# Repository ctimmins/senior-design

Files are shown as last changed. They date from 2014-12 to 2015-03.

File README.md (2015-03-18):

# SENIOR DESIGN Fall 2014 - Winter 2015
##Various files for the projects throughout senior design
###Agricultural Monitoring System
Our senior design project
###Magnetometer
A silly little project in Fall quarter to establish i2c communication between a magnetometer and psoc5 dev kit
###Check out my [website](www.chadtimmins.com) for further updates!

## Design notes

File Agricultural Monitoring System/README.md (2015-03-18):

<!-- START doctoc generated TOC please keep comment here to allow auto update -->
<!-- DON'T EDIT THIS SECTION, INSTEAD RE-RUN doctoc TO UPDATE -->
**Table of Contents**  *generated with [DocToc](https://github.com/thlorenz/doctoc)*

- [System for Temperature and Evapotranspiration Monitoring (STEM)](#system-for-temperature-and-evapotranspiration-monitoring-stem)
  - [Abstract](#abstract)
  - [Marketing Video](#marketing-video)
  - [Features/Components](#featurescomponents)
      - [PSoC5](#psoc5)
      - [Soil Sensors](#soil-sensors)
      - [Infrared Sensor](#infrared-sensor)
      - [XBee Wireless Radio](#xbee-wireless-radio)
      - [Battery System](#battery-system)
      - [Low Power Consumption](#low-power-consumption)
      - [Beaglebone Black](#beaglebone-black)
      - [Data Store](#data-store)
      - [Web Application and Synchronized Data](#web-application-and-synchronized-data)
      - [Analytics Framework](#analytics-framework)
  - [Future Improvements](#future-improvements)
  - [User Manual](#user-manual)
      - [STEM](#stem)
      - [Beaglebone](#beaglebone)
      - [Firebase](#firebase)
      - [Web Application](#web-application)

<!-- END doctoc generated TOC please keep comment here to allow auto update -->

#System for Temperature and Evapotranspiration Monitoring (STEM)

##Abstract
Monitoring plant health and conserving water are two important considerations in regards to agriculture, especially given the current drought. Plants take in water through rainfall and regular watering and lose water through transpiration. If growers can quantify the amount of water that is available to the plant and how much the plant loses through transpiration, they can irrigate more efficiently. STEM accomplishes both of these goals by monitoring soil moisture and temperature at different depths in the ground around a plant.  STEM also observes the leaf temperature of the plant, which correlates to whether or not the stomata are opened or closed and thus whether or not water is evaporating from the leaves.

The board in the field sends the captured data wirelessly to a coordinator which then uploads the data to a remote database.  From this point, growers can view the data using our web application on a computer or tablet.

##Marketing Video

STEM's Marketing Video (http://www.youtube.com/watch?v=bQJXwqZNXdE)

##Drawings of Systems and Subsystems

##Features/Components
####PSoC5
32 bit ARM Cortex M0 based programmable system on chip a.k.a. the brains of each node.
####Soil Sensors
The multi-level installation of subterraneous sensors gives the user a soil moisture and temperature profile and is useful for monitoring the progression of the water-front.  In other words, our system is able to track how water flows through soil and the conditions that cause it do so.  The soil moisture sensors use transmission line techniques to acquire volumetric water content and are immune to inaccurate measurements due to varying levels of salinity.
####Infrared Sensor
The mounted infrared camera gives the user the ability to detect changes in leaf temperature as a function of time. This is used to determine when the stomates in the leaf closes in the day, which marks the point where the plant stops losing water.
####XBee Wireless Radio
XBee radios are low energy, low bandwidth radios that have a range of around 300 feet.
####Battery System
The device is powered by a 2500 mAh Li-po battery. The battery can be recharged through an external solar panel or a USB phone charger. A analog to digital converter is placed to measure the health of the battery, thereby alerting the user that the battery is low.
####Low Power Consumption
Sleep timers were implemented to reduce overall power consumption. The board itself wakes up roughly every 4 seconds, but only takes and transmits measurements periodically. The frequency of message transmittance is user defined and can easily be adjusted depending on the application.
####Beaglebone Black
We used TI’s Beaglebone Black as the XBee coordinator and internet gateway. An XBee radio was mounted to the Beaglebone and Python scripts were developed to handle all communication to and from the wireless sensors. It also maintains information about multiple nodes such as battery status, and various IR configuration settings. Additional scripts were developed for uploading our data to a secure database (Firebase).
The decision to go with a linux micro computer over Digi’s ConnectPort and proprietary Device Cloud was due to the difficulty of integrating a custom user interface with Digi’s services.
####Data Store
We used Firebase to collect and manage all data.  Firebase was chosen for its simplicity in uploading and retrieving data.  It also provides an easy to use dashboard to manage, view, and download all data.
####Web Application and Synchronized Data
Our web application, along with Firebase as a backend, serves as a simple alternative to Etherios Device Cloud.  Firebase and the relevant javascript API’s allow for real time data synchronization across devices.  This means the user can see live updates of sensor data without having to refresh the page. 
####Analytics Framework
TBD

##Future Improvements

##User Manual
####STEM

####Beaglebone

####Firebase

####Web Application

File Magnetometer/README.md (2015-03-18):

#Driver and GUI for MAG3110
Uses XBee and Matlab to send commands and receive data from magnetometer connected to psoc5
Credit: [Sean Alling](https://github.com/oceanofthelost)

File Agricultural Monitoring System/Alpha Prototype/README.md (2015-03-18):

<!-- START doctoc generated TOC please keep comment here to allow auto update -->
<!-- DON'T EDIT THIS SECTION, INSTEAD RE-RUN doctoc TO UPDATE -->
**Table of Contents**  *generated with [DocToc](https://github.com/thlorenz/doctoc)*

- [Alpha Prototype](#alpha-prototype)
  - [The first hardware prototype of the agricultural monitoring system](#the-first-hardware-prototype-of-the-agricultural-monitoring-system)
    - [PCB Layout](#pcb-layout)
    - [Bill of Materials](#bill-of-materials)

<!-- END doctoc generated TOC please keep comment here to allow auto update -->

#Alpha Prototype
##The first hardware prototype of the agricultural monitoring system
###PCB Layout
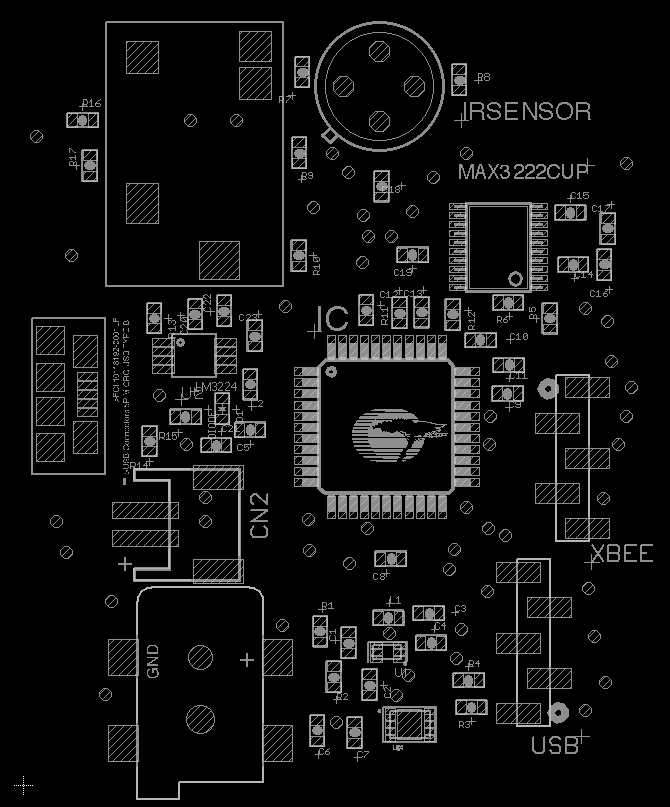
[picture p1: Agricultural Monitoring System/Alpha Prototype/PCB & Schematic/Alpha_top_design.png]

###Bill of Materials
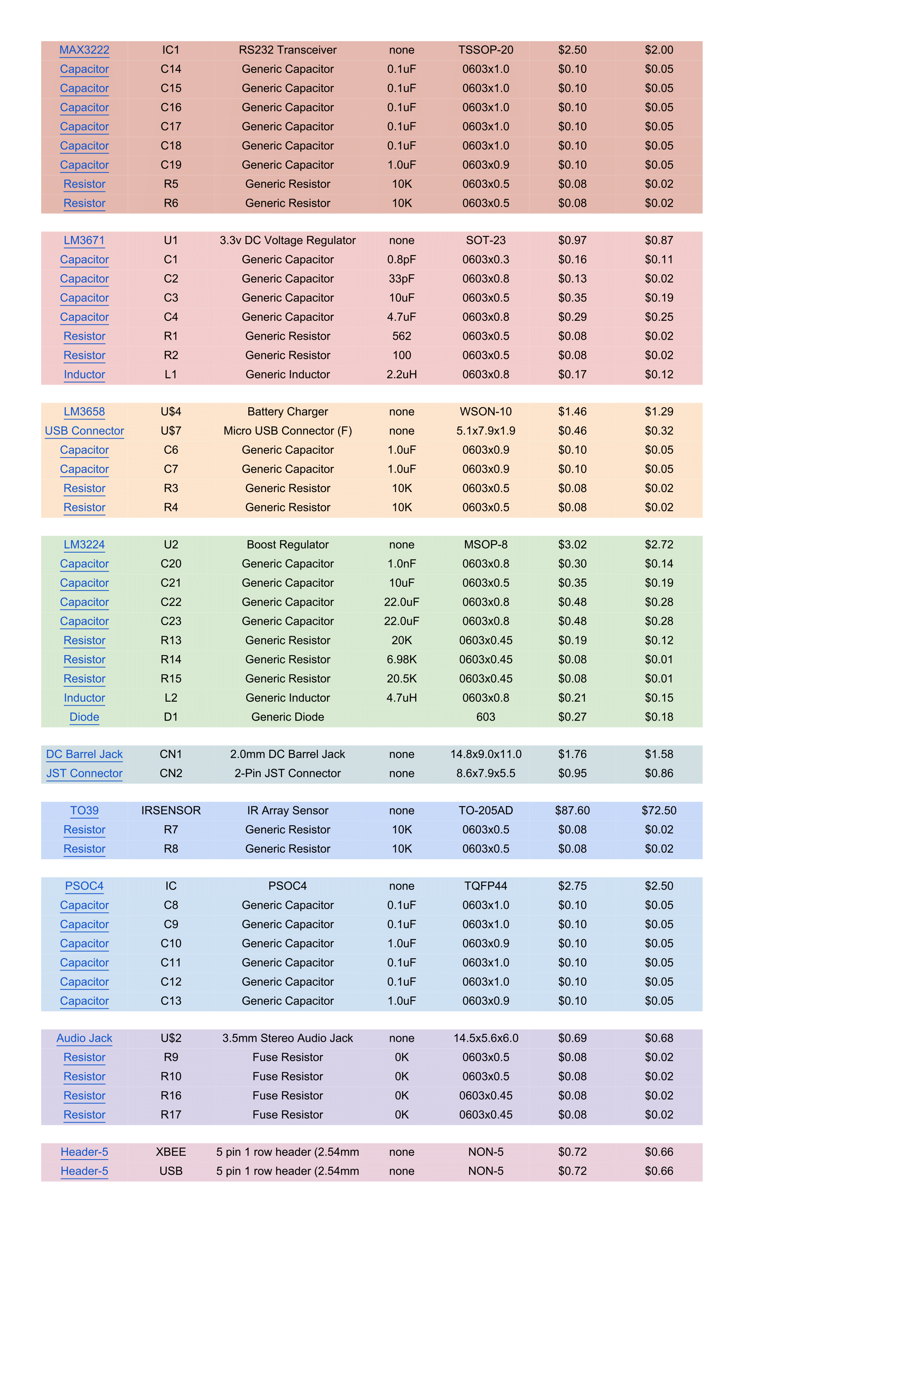
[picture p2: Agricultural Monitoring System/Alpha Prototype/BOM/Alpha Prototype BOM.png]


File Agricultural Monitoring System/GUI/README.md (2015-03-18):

<!-- START doctoc generated TOC please keep comment here to allow auto update -->
<!-- DON'T EDIT THIS SECTION, INSTEAD RE-RUN doctoc TO UPDATE -->
**Table of Contents**  *generated with [DocToc](https://github.com/thlorenz/doctoc)*

- [Graphical User Interface](#graphical-user-interface)
    - [Technologies](#technologies)

<!-- END doctoc generated TOC please keep comment here to allow auto update -->

#Graphical User Interface

###Technologies
* **Firebase** - Backend as a Service to support real time updates from sensors.  3
* **Device Cloud** - Digi's proprietary eco system for monitoring connected devices.  Digi provides a RESTful API that the client-side application will make use of

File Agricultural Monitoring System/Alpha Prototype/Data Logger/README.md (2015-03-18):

<!-- START doctoc generated TOC please keep comment here to allow auto update -->
<!-- DON'T EDIT THIS SECTION, INSTEAD RE-RUN doctoc TO UPDATE -->
**Table of Contents**  *generated with [DocToc](https://github.com/thlorenz/doctoc)*

- [Data Logger for Moisture Sensors](#data-logger-for-moisture-sensors)
  - [SDI-12 Communication](#sdi-12-communication)
    - [Overview](#overview)
    - [Advantages](#advantages)
  - [DDI-Serial Communication](#ddi-serial-communication)
    - [Overview](#overview-1)
    - [Advantages](#advantages-1)
  - [Generalized Schematic of Data Logger System](#generalized-schematic-of-data-logger-system)

<!-- END doctoc generated TOC please keep comment here to allow auto update -->

#Data Logger for Moisture Sensors

##SDI-12 Communication
###Overview
SDI-12 is a standards-based protocol for interfacing sensors to data loggers and data acquisition equipment. Multiple sensors with unique addresses can share a common 3-wire bus (power, ground, and data). Two-way communication between the sensor and logger are possible by sharing the data line for transmit and receive as defined by the standard. Sensor measurements are triggered by protocol command.
###Advantages
* Unique and complex self calibration algorithms can be done in microprocessor- based sensors.
* Sensors can be interchanged without reprogramming the data recorder with calibration or other information.
* Power is supplied to sensors through the interface.

##DDI-Serial Communication
###Overview
The DDI-Serial communications protocol is ideal for systems that have dedicated serial signaling lines for each sensor or use a multiplexer to handle multiple sensors. The serial communications are compatible with many TTL serial implementations that support active-high logic levels using 0-3.6 volts signal levels. When the sensor is first powered, it automatically makes measurements of the integrated transducers then outputs a response over the data line. Systems using this protocol control the sensor excitation to initiate data transfers from the sensor.
###Advantages
* Very easy to interface PSoC to sensor

##Generalized Schematic of Data Logger System
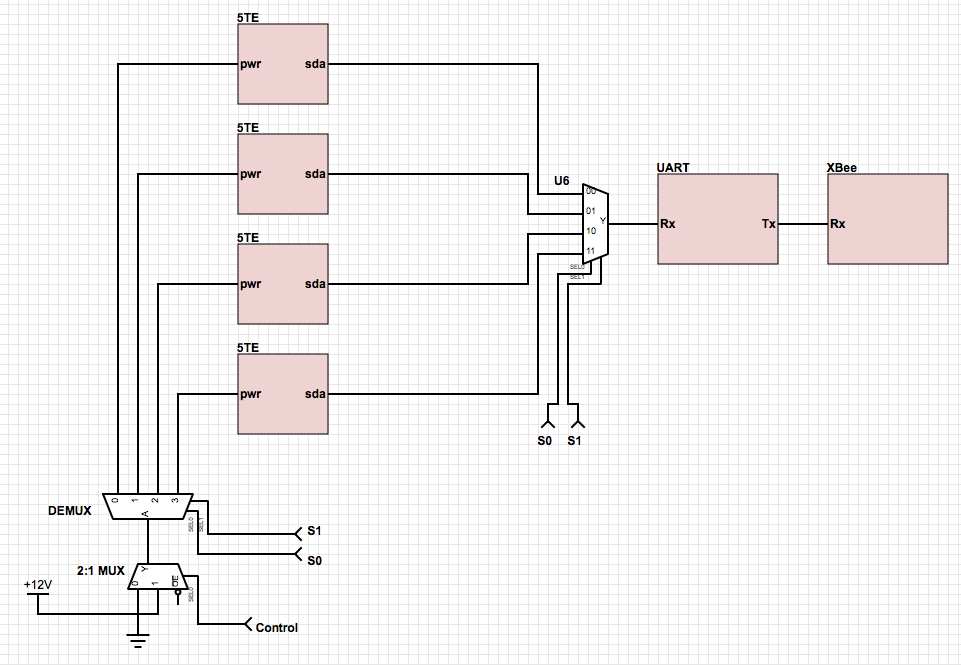
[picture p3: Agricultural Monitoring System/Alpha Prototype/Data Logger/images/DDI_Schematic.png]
alt-tag


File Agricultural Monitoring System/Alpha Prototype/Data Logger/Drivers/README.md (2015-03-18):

<!-- START doctoc generated TOC please keep comment here to allow auto update -->
<!-- DON'T EDIT THIS SECTION, INSTEAD RE-RUN doctoc TO UPDATE -->
**Table of Contents**  *generated with [DocToc](https://github.com/thlorenz/doctoc)*

- [Driver Code for PSoC4 and Decagon 5tm](#driver-code-for-psoc4-and-decagon-5tm)

<!-- END doctoc generated TOC please keep comment here to allow auto update -->

#Driver Code for PSoC4 and Decagon 5tm

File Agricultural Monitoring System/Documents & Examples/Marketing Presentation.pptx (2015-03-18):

## S.T.E.M

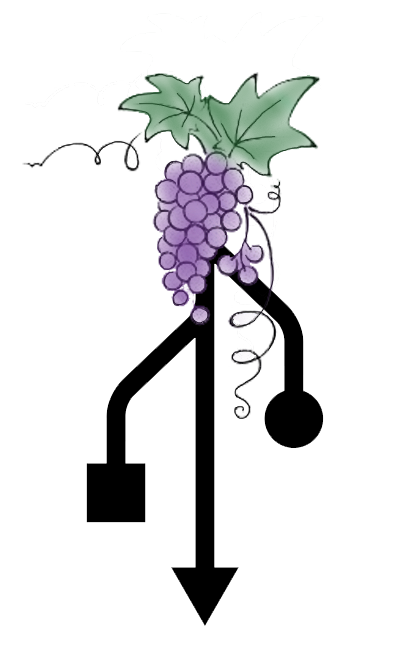
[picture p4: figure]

Team Beta: Advanced Weather Station

Chad Timmins
David Killeen
Erik Zhang
Jeffrey Kung
Robin Johnston

## Why S.T.E.M.?

Against Tule, S.T.E.M.:
- Low Cost vs. $1500
- Lower Price for component replacements vs. $250
- Does not require minimum purchase
- Measures actual soil moisture content
- Measures actual leaf temperature

Against AquaSpy, S.T.E.M.:
- Low Cost vs. $800
- Measures leaf temperature
- Sleeker Design

## Tule’s Design

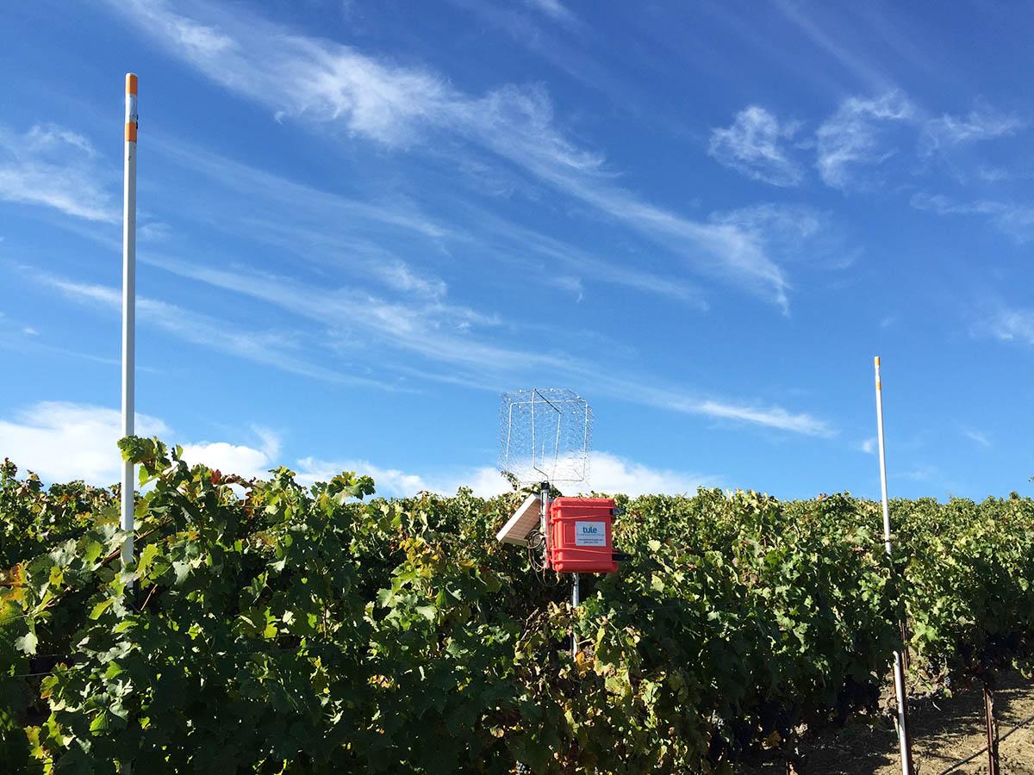
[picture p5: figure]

## AquaSpy’s Design

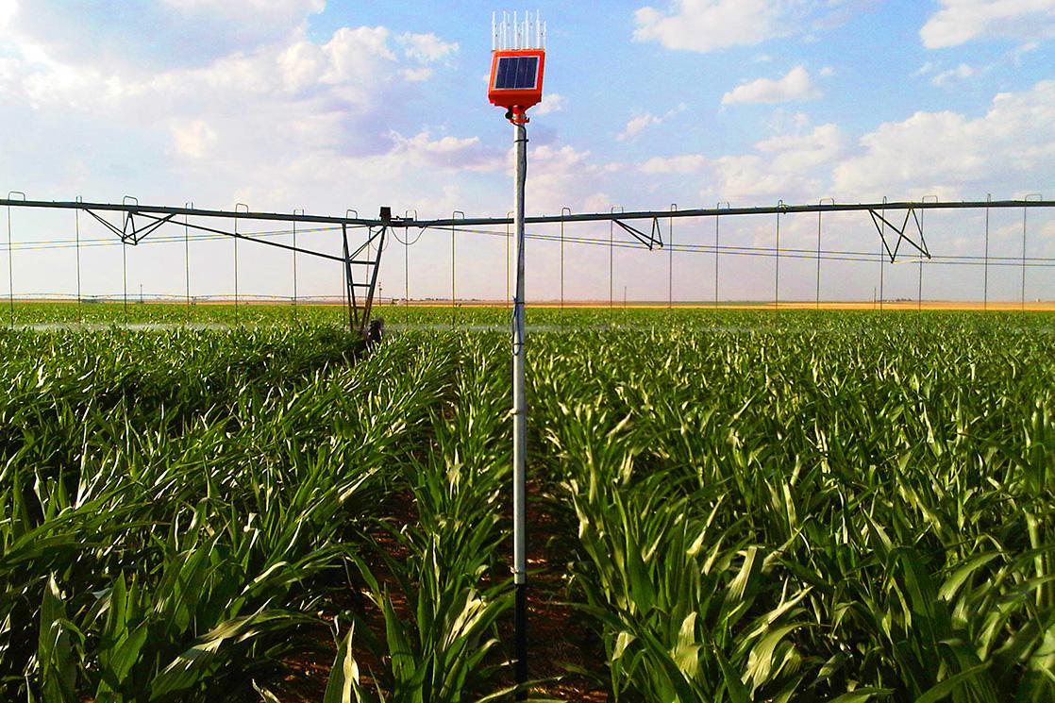
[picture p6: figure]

## Overview

- Monitors soil moisture levels and
leaf temperature
- Cloud storage
- Web interface

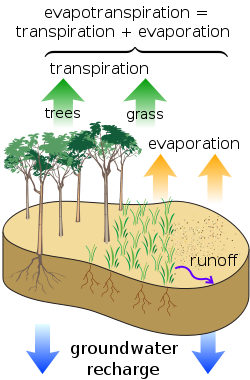
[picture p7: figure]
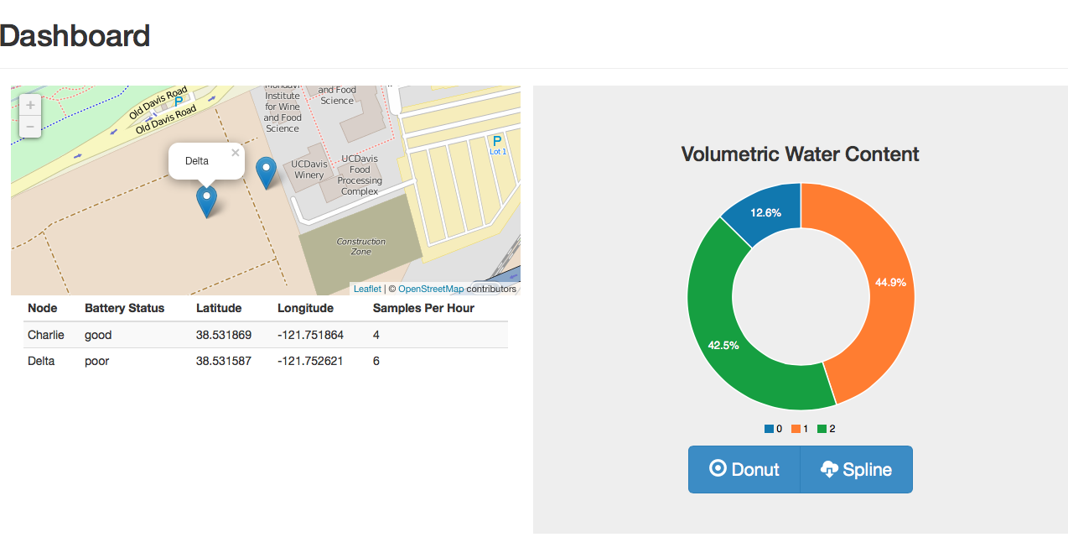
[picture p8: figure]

## Design

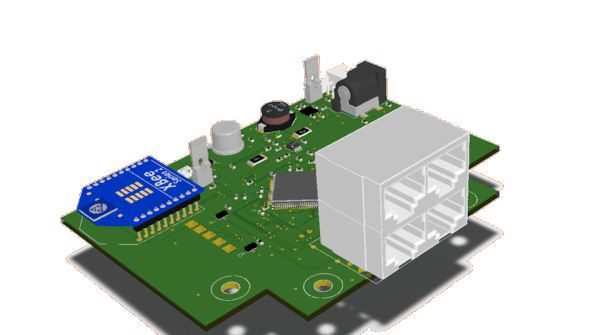
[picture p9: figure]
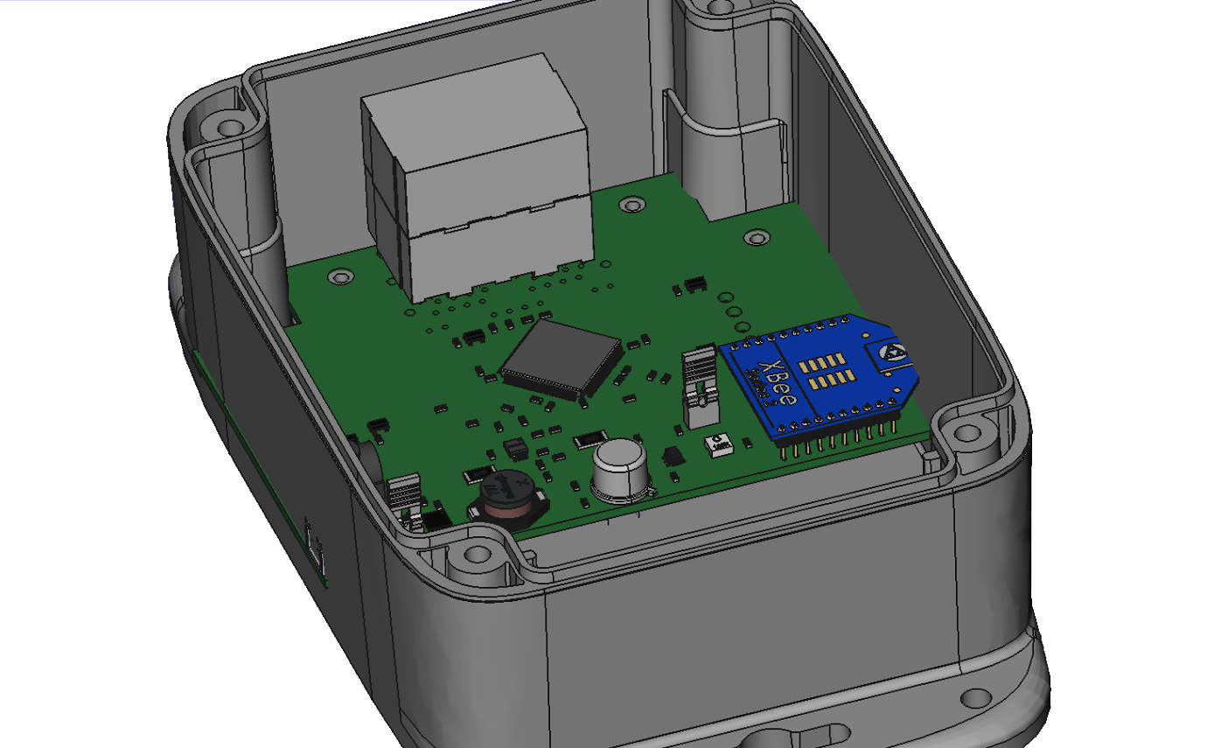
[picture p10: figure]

IR Sensor

DC in

XBee

PSoC 5LP

Ethernet(Vegetronix)

## Power Architecture

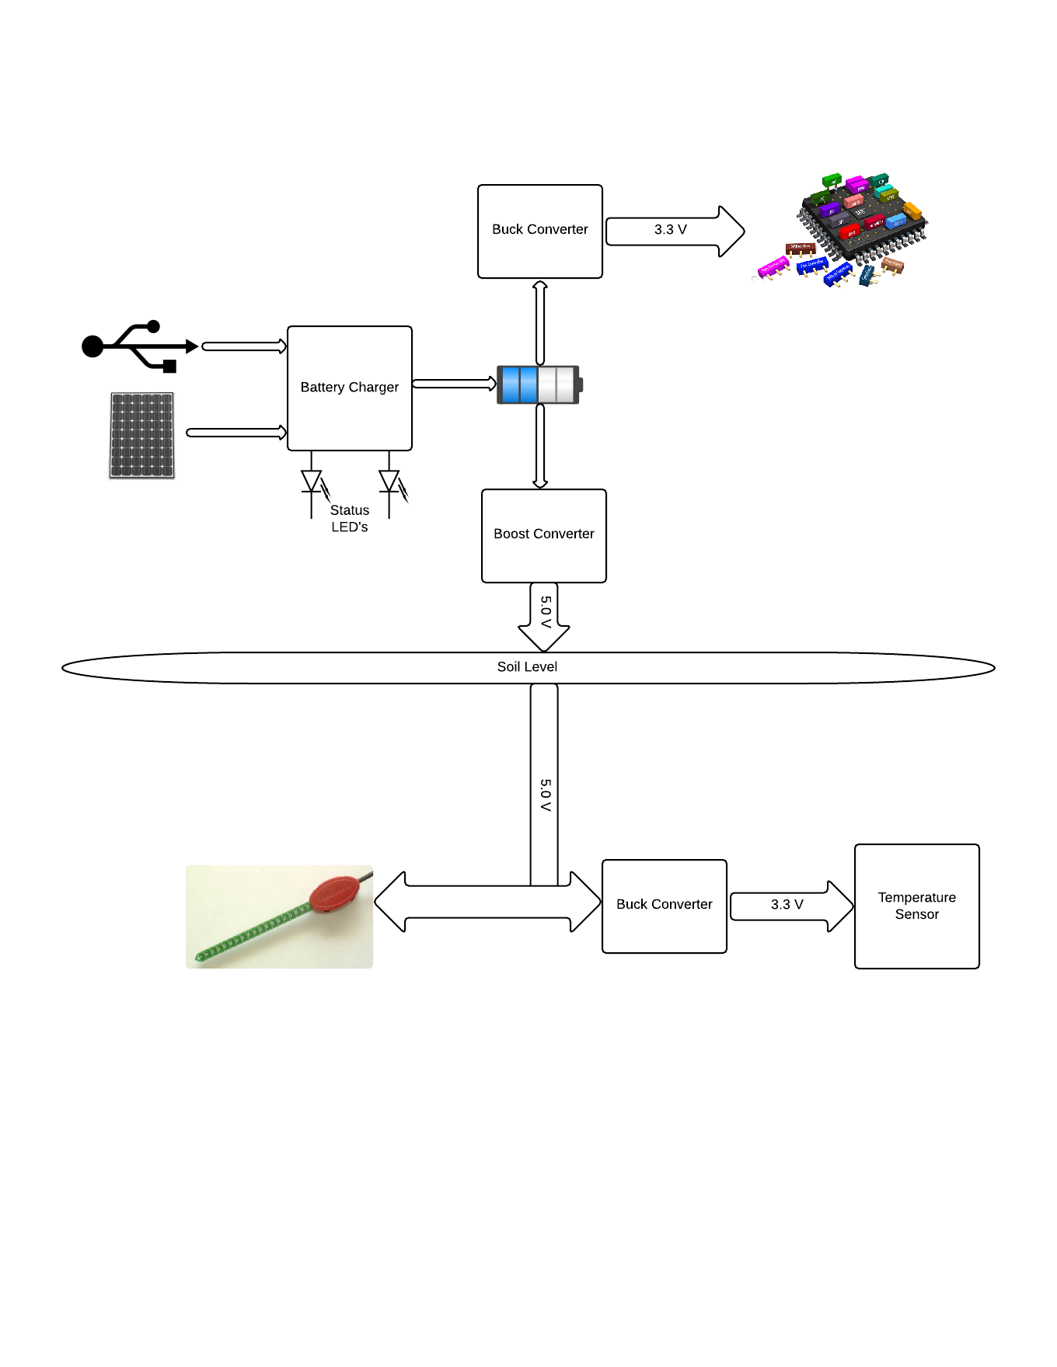
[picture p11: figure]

## Communications

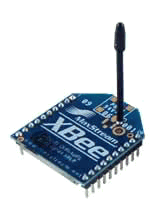
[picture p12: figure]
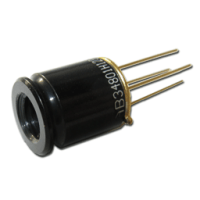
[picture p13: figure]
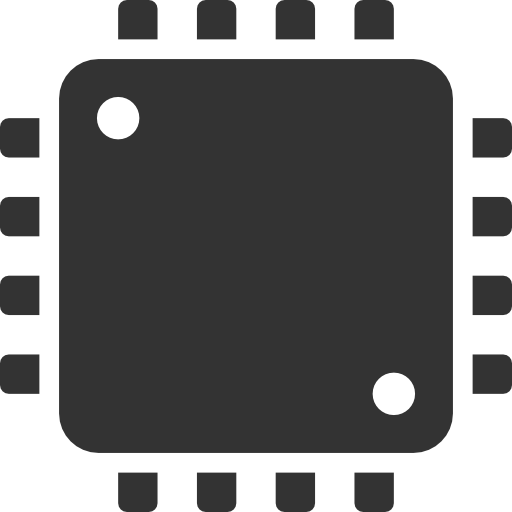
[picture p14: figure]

i2c

uart

i2c

i2c

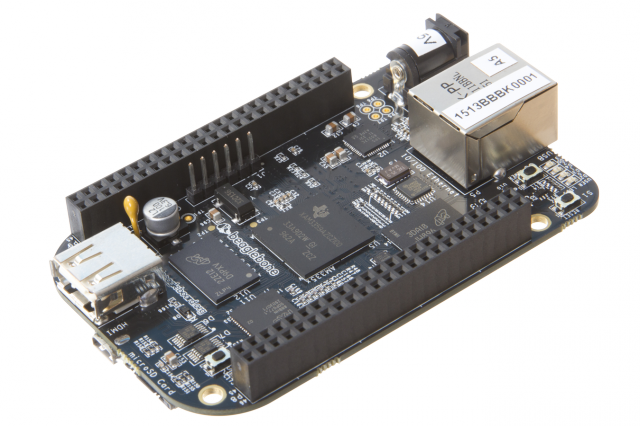
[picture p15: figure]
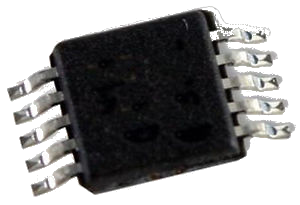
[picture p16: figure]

adc

## Sensors

MLX90620 IR Temperature | Vegetronix Volumetric Water Content | LM75BGD Temperature
Operating Temperature -40ºC to 85ºC Object Temperature-50ºC to 300ºC 16 x 4 Array 60° FOV Accuracy of ±1°C ±3% $88 | Operating Temperature -40ºC to 85ºC Buriable and waterproof Insensitive to salinity Corrosion resistant Accuracy of 2% at 25°C $38 - $54 Each | Operating Temperature -55ºC to 125ºC +/- 2ºC from 25ºC to 100ºC +/- 3ºC from 55ºC to 125ºC temperature resolution of 0.125ºC $0.59 Each

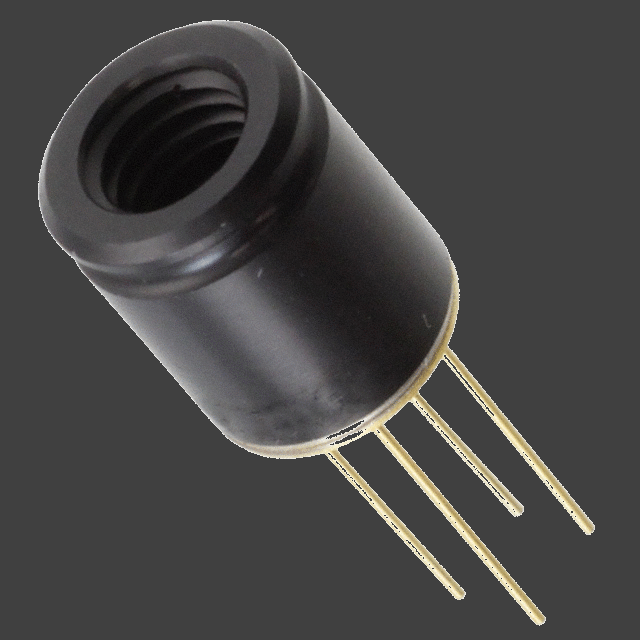
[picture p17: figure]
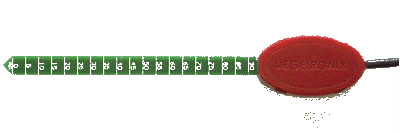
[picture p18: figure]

## State Machine

## Power Consumption

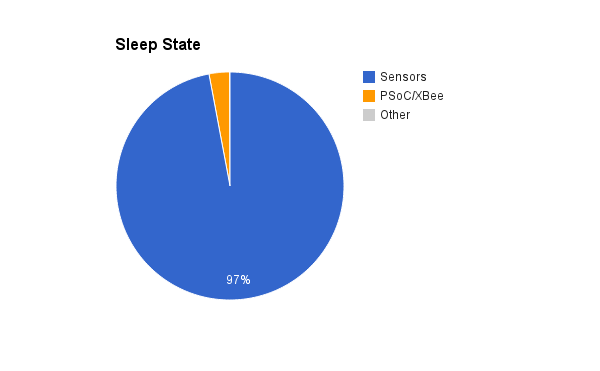
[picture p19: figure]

1.36 mW x 60 min = 1.36 mWh

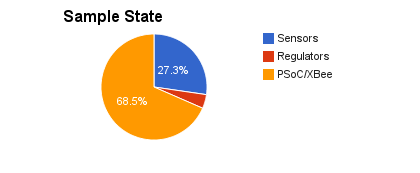
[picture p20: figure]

177.7 mW x 1 sec x 4 = .19744 mWh

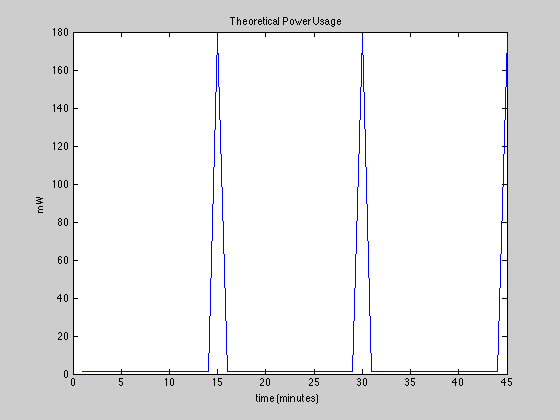
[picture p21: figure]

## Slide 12

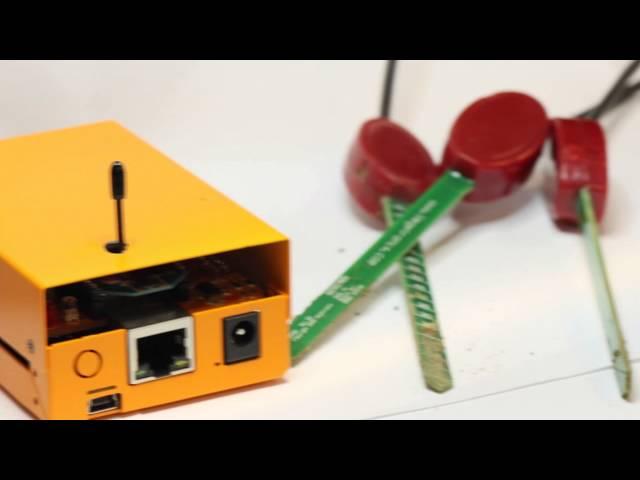
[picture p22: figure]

## Acknowledgements

-Professor André Knoesen
-Dr. Jean-Jacques Lambert
-Nick Hosein and Saneel Khatri

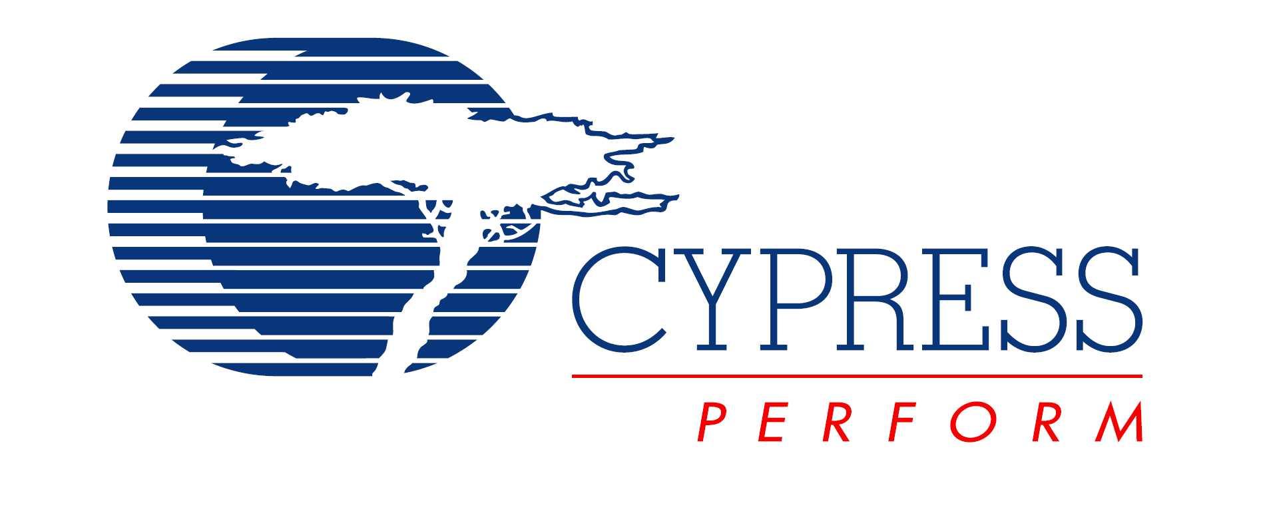
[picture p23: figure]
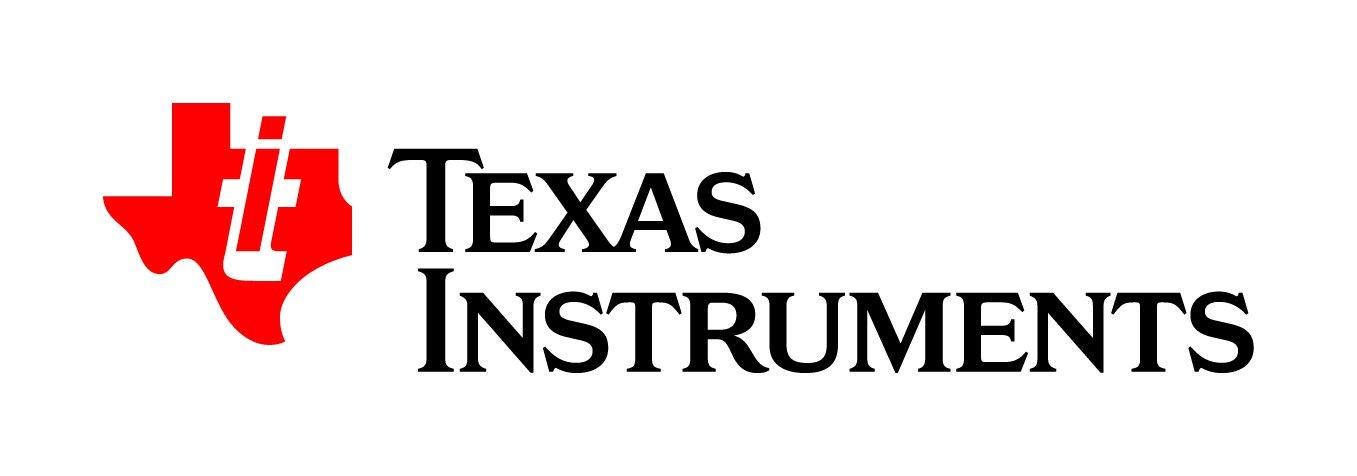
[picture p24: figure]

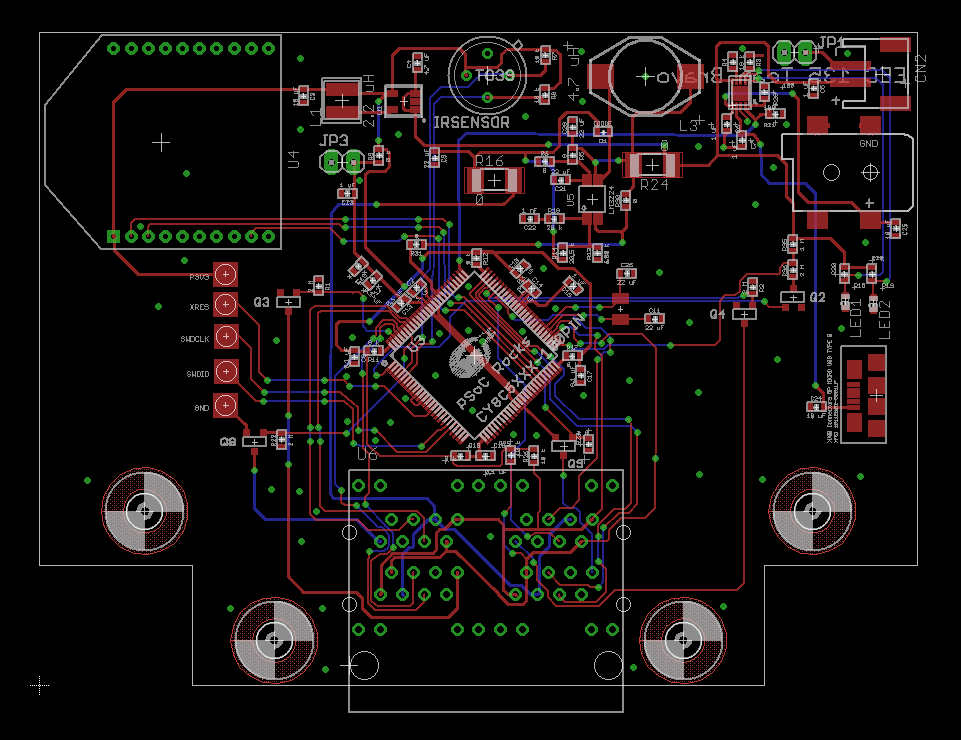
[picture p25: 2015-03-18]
Agricultural Monitoring System/Release/images/Screen Shot 2015-03-14 at 7.27.00 PM.png

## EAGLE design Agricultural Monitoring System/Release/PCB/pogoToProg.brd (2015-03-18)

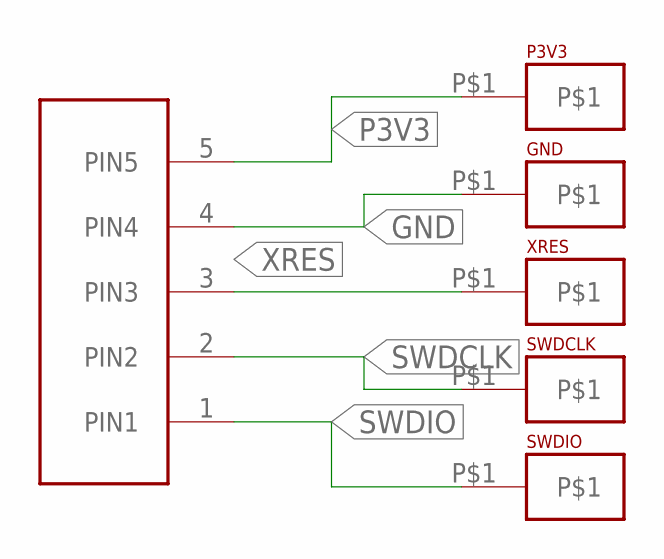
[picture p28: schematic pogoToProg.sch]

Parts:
GND: POGO-MATING
P3V3: POGO-MATING
SWDCLK: POGO-MATING
SWDIO: POGO-MATING
U$1: HEADER-5; NON-5
XRES: POGO-MATING

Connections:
GND: GND.P$1, U$1.4 (PIN4)
P3V3: P3V3.P$1, U$1.5 (PIN5)
SWDCLK: SWDCLK.P$1, U$1.2 (PIN2)
SWDIO: SWDIO.P$1, U$1.1 (PIN1)
XRES: U$1.3 (PIN3), XRES.P$1

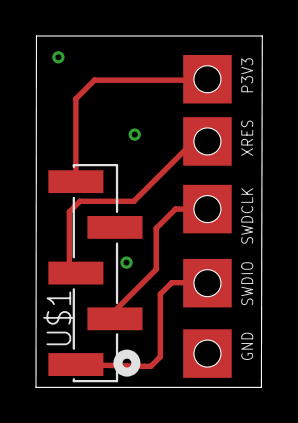
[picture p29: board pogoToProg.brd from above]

Board: 2 copper layers, 12.6 x 19.5 mm, 6 parts (0 on the bottom side), 5 nets.

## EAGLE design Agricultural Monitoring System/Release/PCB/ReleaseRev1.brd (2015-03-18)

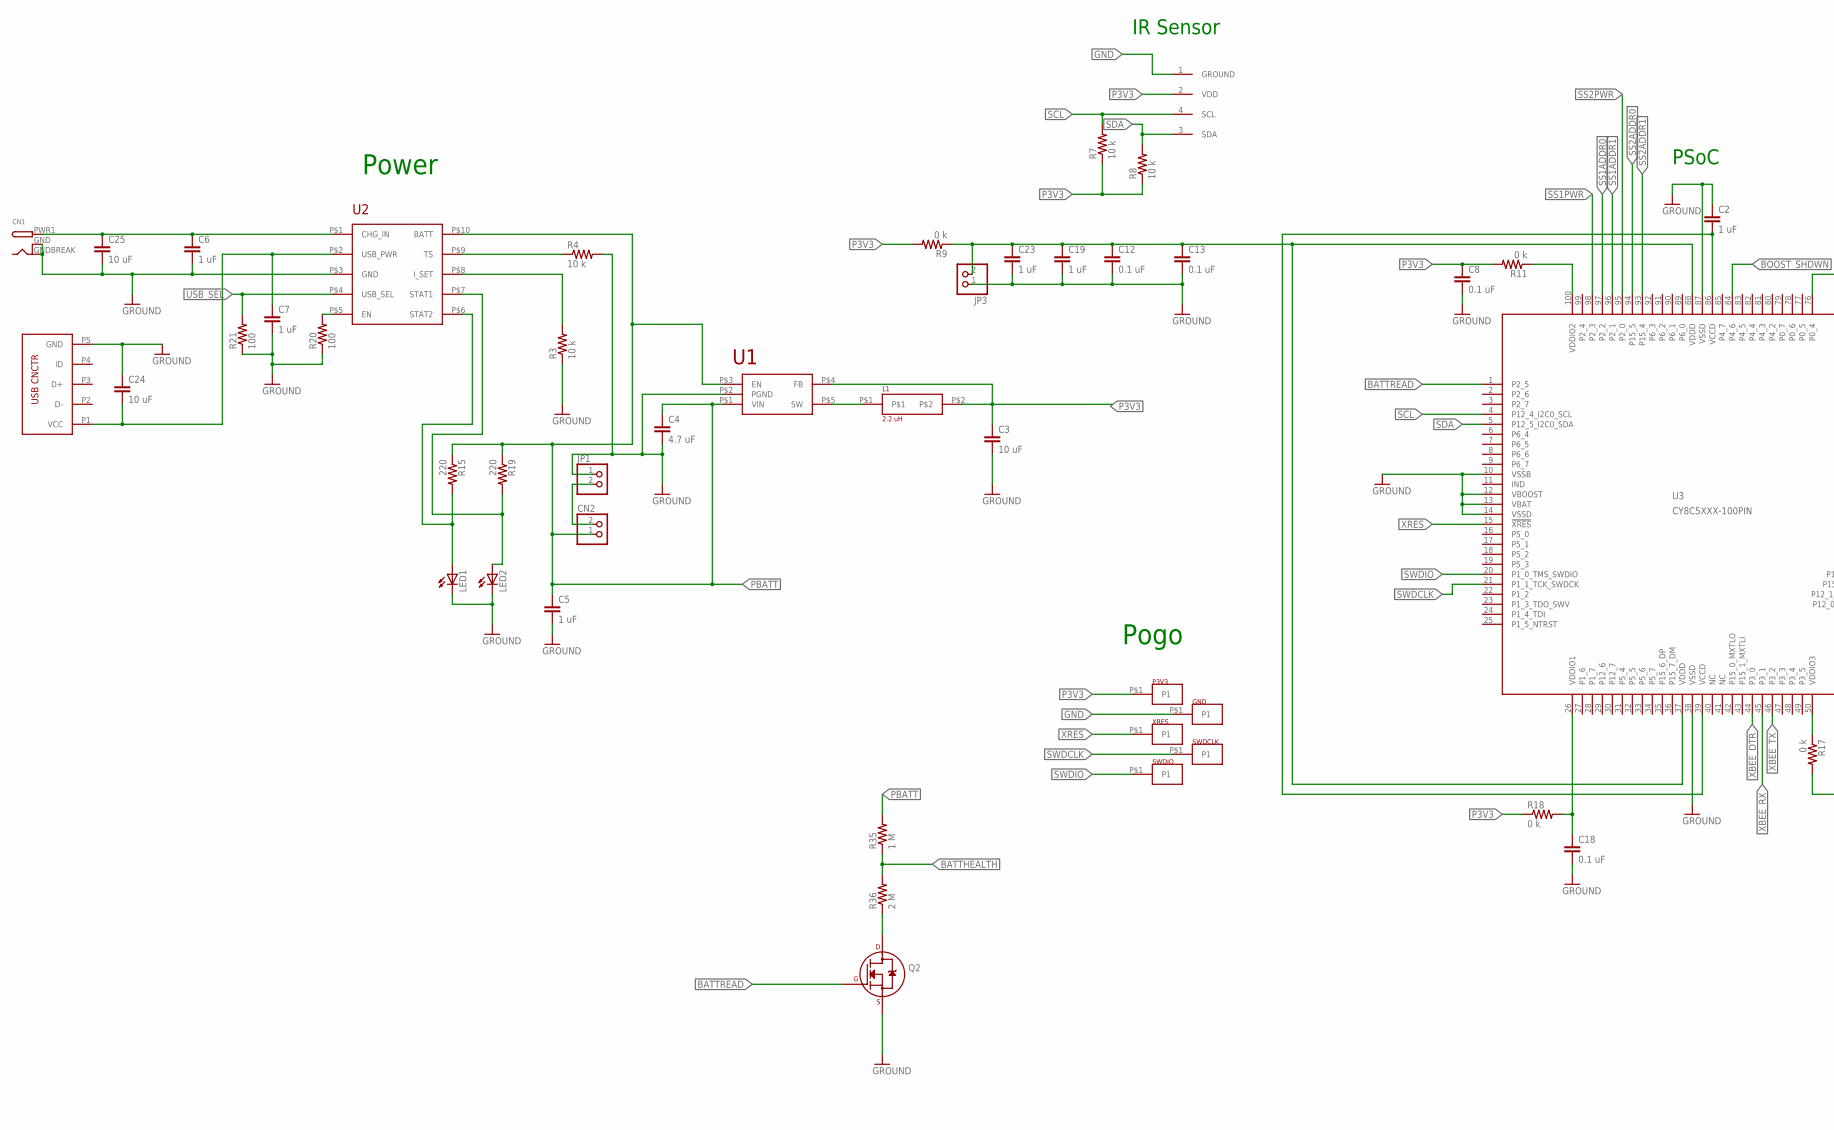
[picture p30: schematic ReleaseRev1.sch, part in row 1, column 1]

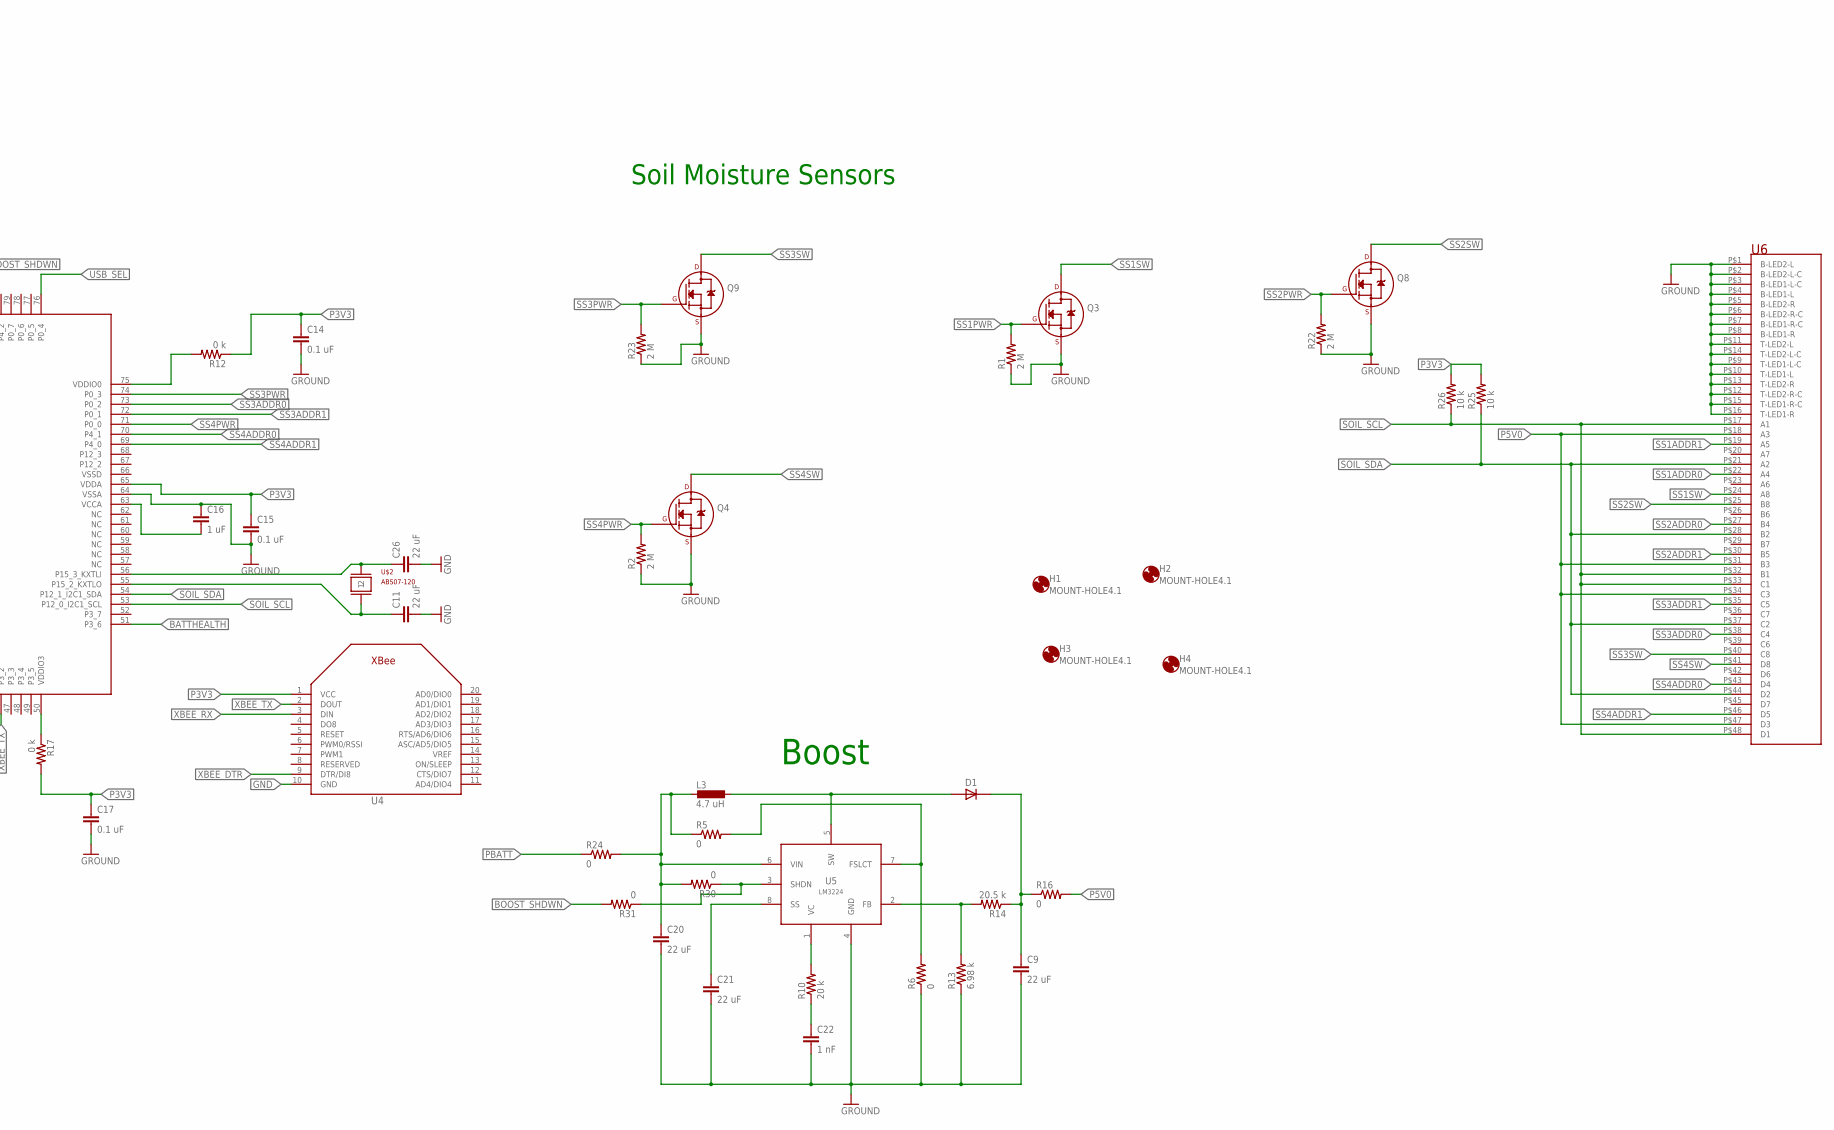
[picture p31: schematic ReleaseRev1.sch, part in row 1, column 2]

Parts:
C2, C5, C6, C7, C16, C19, C23: 1 uF; 0603
C3, C24, C25: 10 uF; 0603
C4: 4.7 uF; 0603
C8, C12, C13, C14, C15, C17, C18: 0.1 uF; 0603
C9, C11, C20, C21, C26: 22 uF; 0603
C22: 1 nF; 0603
CN1: DCBARRELSMT; DCJACK_2MM_SMT
CN2: JST_2PIN-SMT-RA; JST-PH-2-SMT-RA
D1: DIODE; 0603-LED
GND: POGO-MOUNTING
H1, H2, H3, H4: MOUNT-HOLE4.1; 4,1
IRSENSOR: TO39
JP1, JP3: PINHD-1X2; 1X02
L1: LPO3310
L3: 4.7 uH; DO3316P
LED1, LED2: LEDCHIP-LED0603; CHIP-LED0603
P3V3: POGO-MOUNTING
Q2, Q3, Q4, Q8, Q9: 2N7000_SOT23; SOT-23
R1, R2, R22, R23, R36: 2 M; 0603
R3, R4, R7, R8, R25, R26: 10 k; 0603
R5, R6, R30, R31: 0; 0603
R9, R11, R12, R17, R18: 0 k; 0603
R10: 20 k; 0603
R13: 6.98 k; 0603
R14: 20.5 k; 0603
R15, R19: 220; 0603
R16, R24: 0; R2010
R20, R21: 100; 0603
R35: 1 M; 0603
SWDCLK: POGO-MOUNTING
SWDIO: POGO-MOUNTING
U1: LM3671-407564
U2: LM3658
U3: CY8C5XXX-100PIN; TQFP-14X14-100
U4: XBEE
U5: LM3224; MSOP-8
U6: RJSAE-5380-04
U$1: FCI10118192-0001LF
U$2: ABS07-120; 2-SMD
XRES: POGO-MOUNTING

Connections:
BATTHEALTH: R35.1, R36.2, U3.51 (P3_6)
BATTREAD: Q2.1 (G), U3.1 (P2_5)
BOOST_SHDWN: R31.2, U3.84 (P4_6)
GND: C2.1, C3.2, C4.2, C5.2, C6.2, C7.2, C8.2, C9.2, C11.2, C12.2, C13.2, C14.2, C15.2, C16.1, C17.2, C18.2, C19.2, C20.2, C21.2, C22.2, C23.2, C24.1, C25.2, C26.2, CN1.GND (GNDBREAK), CN1.GNDBREAK (GND), GND.P$1, IRSENSOR.1 (GROUND), JP1.1, JP3.1, LED1.C, LED2.C, Q2.2 (S), Q3.2 (S), Q4.2 (S), Q8.2 (S), Q9.2 (S), R1.1, R2.1, R3.1, R4.2, R6.1, R13.1, R20.1, R21.1, R22.1, R23.1, U1.P$2 (PGND), U2.P$3 (GND), U3.10 (VSSB), U3.12 (VBOOST), U3.13 (VBAT), U3.14 (VSSD), U3.38 (VSSD), U3.64 (VSSA), U3.87 (VSSD), U4.10 (GND), U5.4 (GND), U6.P$1 (B-LED2-L), U6.P$2 (B-LED2-L-C), U6.P$3 (B-LED1-L-C), U6.P$4 (B-LED1-L), U6.P$5 (B-LED2-R), U6.P$6 (B-LED2-R-C), U6.P$7 (B-LED1-R-C), U6.P$8 (B-LED1-R), U6.P$9 (T-LED1-L-C), U6.P$10 (T-LED1-L), U6.P$11 (T-LED2-L), U6.P$12 (T-LED2-R-C), U6.P$13 (T-LED2-R), U6.P$14 (T-LED2-L-C), U6.P$15 (T-LED1-R-C), U6.P$16 (T-LED1-R), U$1.P5 (GND)
unnamed: R20.2, U2.P$5 (EN)
unnamed: R3.2, U2.P$8 (I_SET)
unnamed: C21.1, U5.8 (SS)
unnamed: C26.1, U3.56 (P15_3_KXTLI), U$2.1
unnamed: C6.1, C25.1, CN1.PWR1 (PWR), U2.P$1 (CHG_IN)
unnamed: C18.1, R18.2, U3.26 (VDDIO1)
unnamed: D1.A, L3.2, U5.5 (SW)
unnamed: R4.1, U2.P$9 (TS)
unnamed: R10.2, U5.1 (VC)
unnamed: CN2.2 (1), JP1.2
unnamed: C22.1, R10.1
unnamed: R13.2, R14.2, U5.2 (FB)
unnamed: C2.2, U3.39 (VCCD), U3.86 (VCCD)
unnamed: Q2.3 (D), R36.1
unnamed: C16.2, U3.63 (VCCA)
unnamed: R5.2, R6.2, U5.7 (FSLCT)
unnamed: C11.1, U3.55 (P15_2_KXTLO), U$2.2
unnamed: R12.2, U3.75 (VDDIO0)
unnamed: R11.1, U3.100 (VDDIO2)
unnamed: C12.1, C13.1, C19.1, C23.1, JP3.2, R9.1, U3.37 (VDDD), U3.88 (VDDD)
unnamed: R17.1, U3.50 (VDDIO3)
unnamed: LED2.A, R19.2, U2.P$7 (STAT1)
unnamed: LED1.A, R15.2, U2.P$6 (STAT2)
unnamed: L1.P$1, U1.P$5 (SW)
unnamed: R30.1, R31.1, U5.3 (SHDN)
P: C20.1, L3.1, R5.1, R24.2, R30.2, U5.6 (VIN)
P3V3: C3.1, C8.1, C14.1, C15.1, C17.1, IRSENSOR.2 (VDD), L1.P$2, P3V3.P$1, R7.1, R8.1, R9.2, R11.2, R12.1, R17.2, R18.1, R25.2, R26.2, U1.P$4 (FB), U3.65 (VDDA), U4.1 (VCC)
P5: C9.1, D1.C, R14.1, R16.1
P5V0: R16.2, U6.P$18 (A3), U6.P$31 (B3), U6.P$34 (C3), U6.P$47 (D3)
PBATT: C4.1, C5.1, CN2.1 (2), R15.1, R19.1, R24.1, R35.2, U1.P$1 (VIN), U1.P$3 (EN), U2.P$10 (BATT)
SCL: IRSENSOR.4 (SCL), R7.2, U3.4 (P12_4_I2C0_SCL)
SDA: IRSENSOR.3 (SDA), R8.2, U3.5 (P12_5_I2C0_SDA)
SOIL_SCL: R26.1, U3.53 (P12_0_I2C1_SCL), U6.P$17 (A1), U6.P$32 (B1), U6.P$33 (C1), U6.P$48 (D1)
SOIL_SDA: R25.1, U3.54 (P12_1_I2C1_SDA), U6.P$21 (A2), U6.P$28 (B2), U6.P$37 (C2), U6.P$44 (D2)
SS1ADDR0: U3.97 (P2_2), U6.P$22 (A4)
SS1ADDR1: U3.96 (P2_1), U6.P$19 (A5)
SS1PWR: Q3.1 (G), R1.2, U3.98 (P2_3)
SS1SW: Q3.3 (D), U6.P$24 (A8)
SS2ADDR0: U3.94 (P15_5), U6.P$27 (B4)
SS2ADDR1: U3.93 (P15_4), U6.P$30 (B5)
SS2PWR: Q8.1 (G), R22.2, U3.95 (P2_0)
SS2SW: Q8.3 (D), U6.P$25 (B8)
SS3ADDR0: U3.73 (P0_2), U6.P$38 (C4)
SS3ADDR1: U3.72 (P0_1), U6.P$35 (C5)
SS3PWR: Q9.1 (G), R23.2, U3.74 (P0_3)
SS3SW: Q9.3 (D), U6.P$40 (C8)
SS4ADDR0: U3.70 (P4_1), U6.P$43 (D4)
SS4ADDR1: U3.69 (P4_0), U6.P$46 (D5)
SS4PWR: Q4.1 (G), R2.2, U3.71 (P0_0)
SS4SW: Q4.3 (D), U6.P$41 (D8)
SWDCLK: SWDCLK.P$1, U3.21 (P1_1_TCK_SWDCK)
SWDIO: SWDIO.P$1, U3.20 (P1_0_TMS_SWDIO)
USB: C7.1, C24.2, U2.P$2 (USB_PWR), U$1.P1 (VCC)
USB_SEL: R21.2, U2.P$4 (USB_SEL), U3.76 (P0_4)
XBEE_DTR: U3.44 (P3_0), U4.9 (DTR/DI8)
XBEE_RX: U3.45 (P3_1), U4.3 (DIN)
XBEE_TX: U3.46 (P3_2), U4.2 (DOUT)
XRES: U3.15 (!XRES!), XRES.P$1

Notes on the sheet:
PSoC
IR Sensor
Boost
Pogo
Power
Soil Moisture Sensors

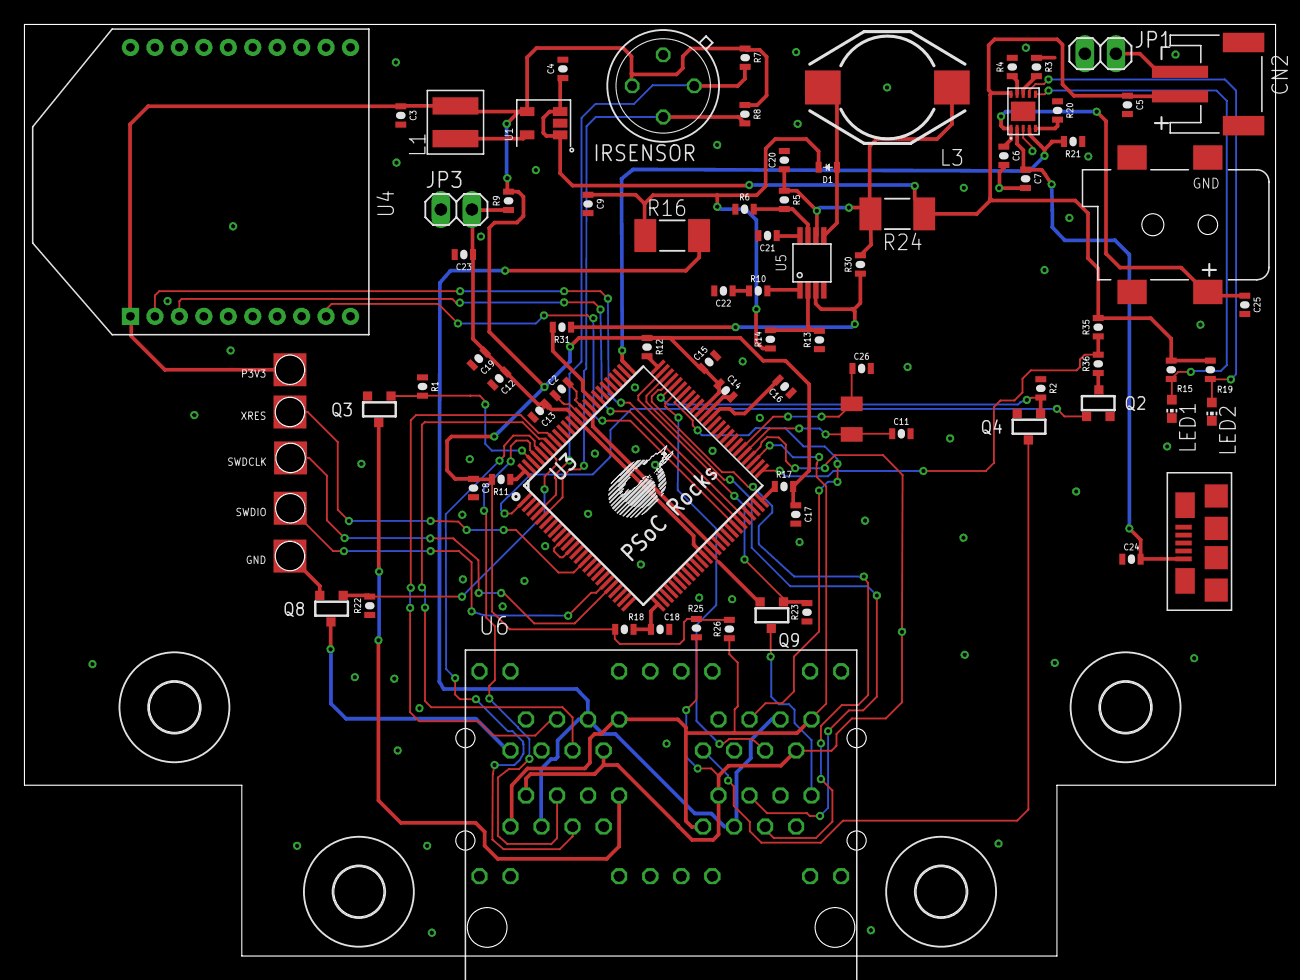
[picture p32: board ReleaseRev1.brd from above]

Board: 2 copper layers, 102.3 x 76.2 mm, 86 parts (0 on the bottom side), 62 nets.

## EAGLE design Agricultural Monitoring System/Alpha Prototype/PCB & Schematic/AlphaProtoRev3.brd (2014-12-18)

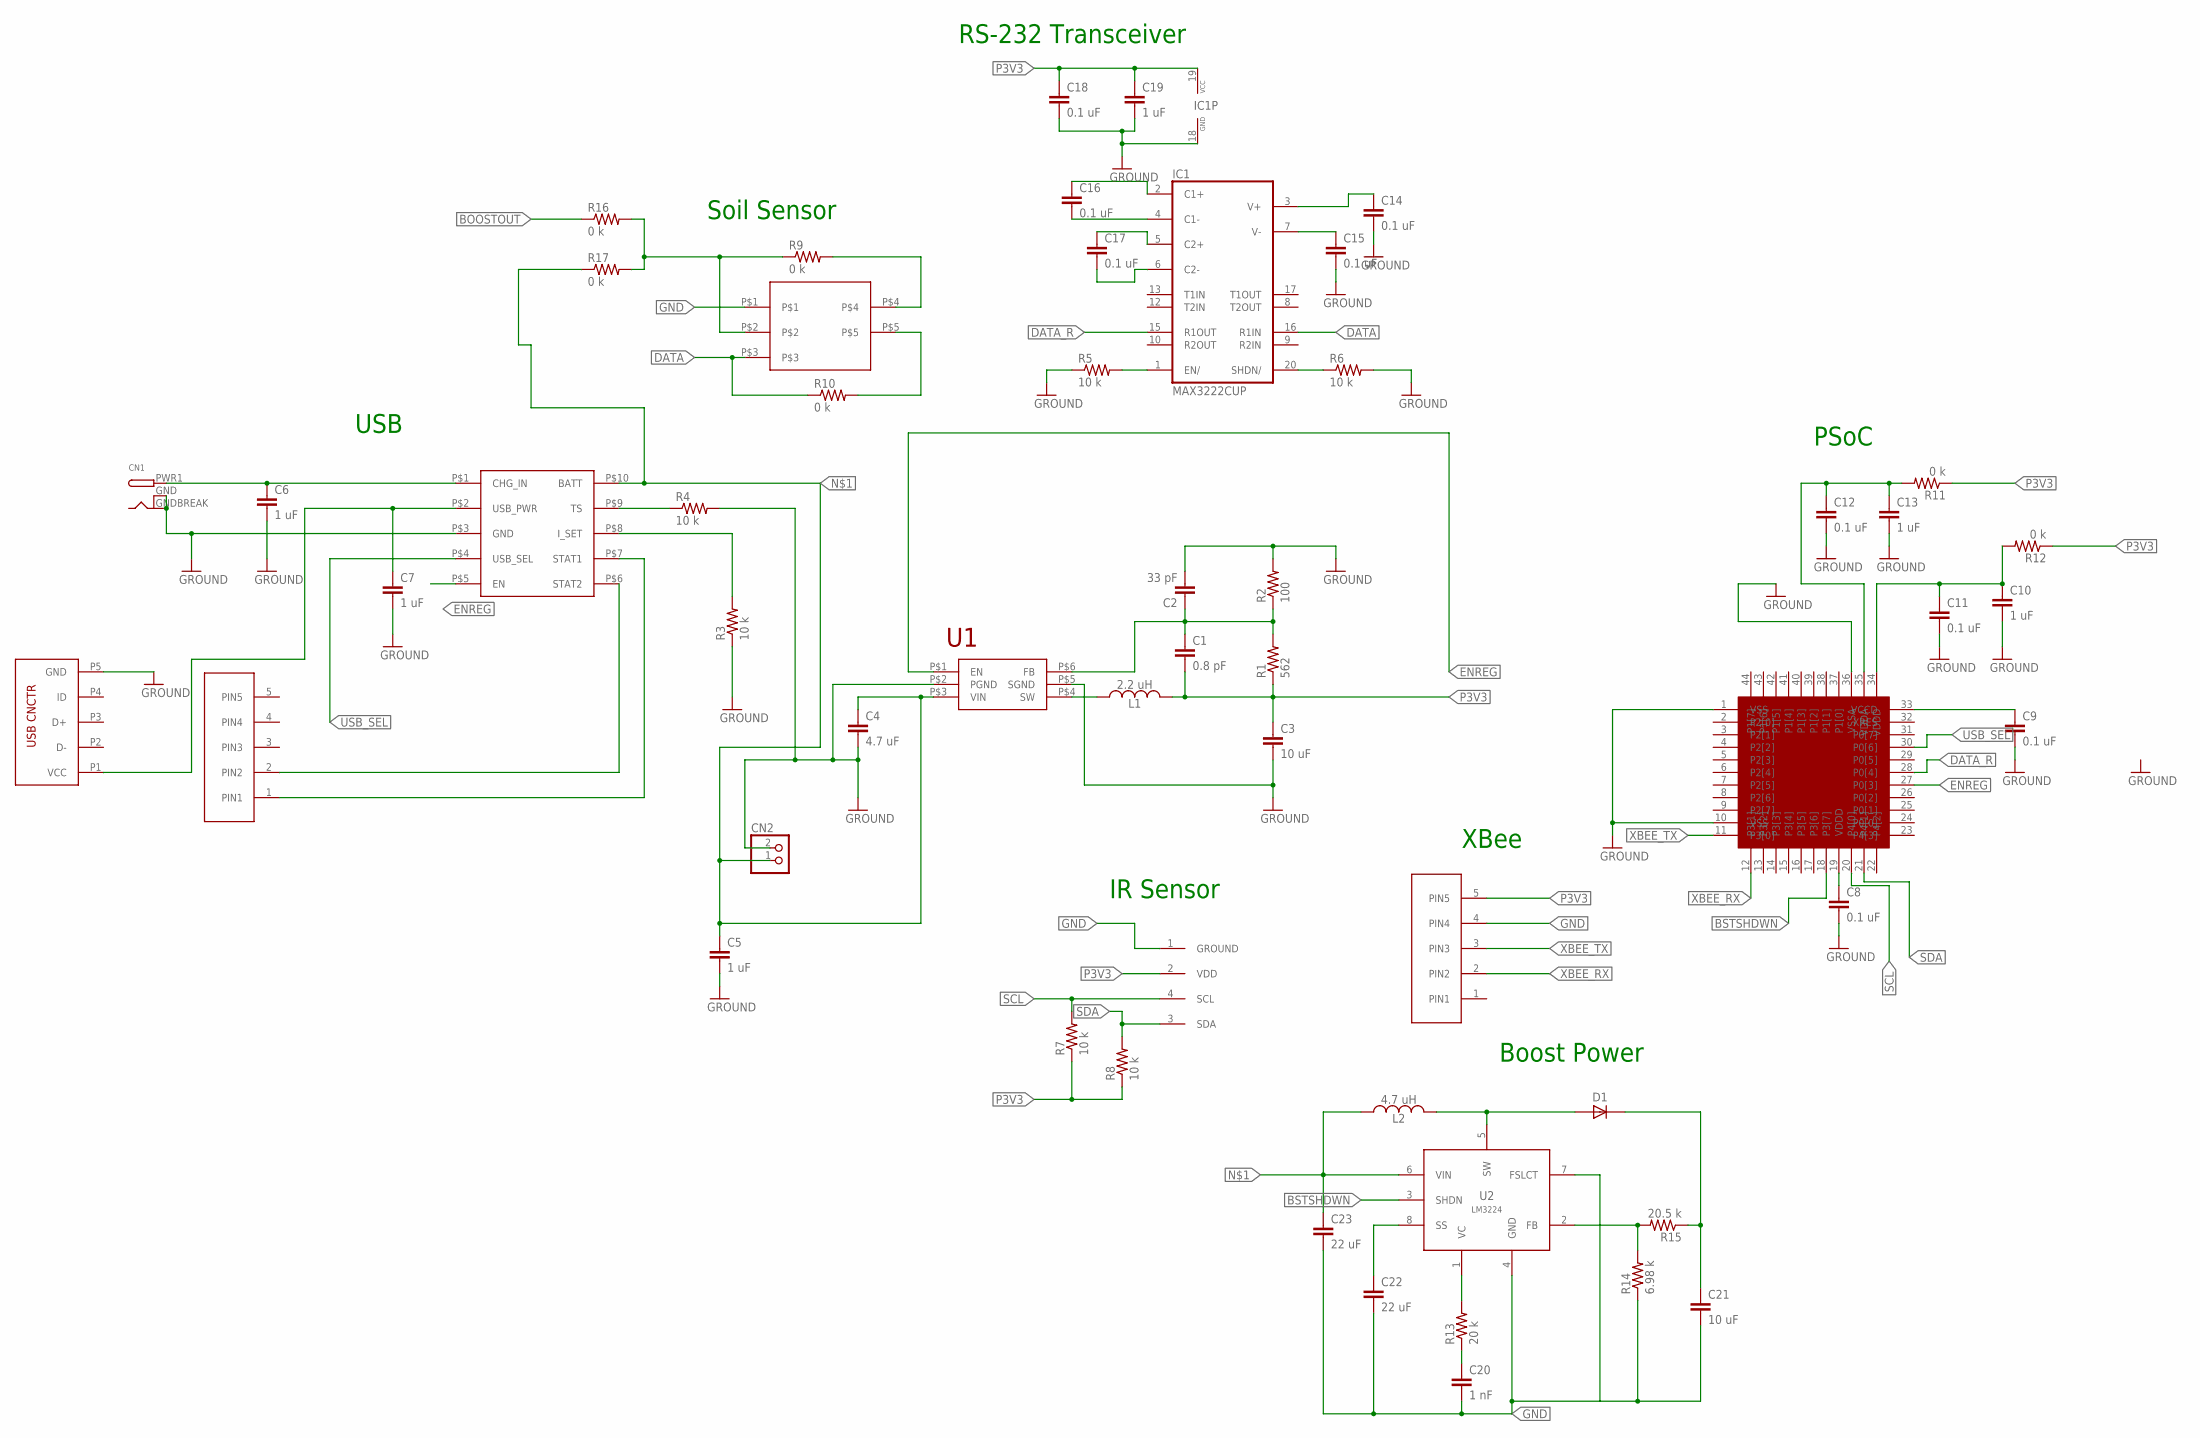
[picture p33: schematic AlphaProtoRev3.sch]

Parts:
C1: 0.8 pF; 0603
C2: 33 pF; 0603
C3, C21: 10 uF; 0603
C4: 4.7 uF; 0603
C5, C6, C7, C10, C13, C19: 1 uF; 0603
C8, C9, C11, C12, C14, C15, C16, C17, C18: 0.1 uF; 0603
C20: 1 nF; 0603
C22, C23: 22 uF; 0603
CN1: DCBARRELSMT; DCJACK_2MM_SMT
CN2: JST_2PIN-SMT-RA; JST-PH-2-SMT-RA
D1: DIODE; 0603-LED
IC: PSOC4FP; TQFP44
IC1: MAX3222CUP; TSSOP20
IRSENSOR: TO39
L1: 2.2 uH; 0603
L2: 4.7 uH; 0603
R1: 562; 0603
R2: 100; 0603
R3, R4, R5, R6, R7, R8: 10 k; 0603
R9, R10, R11, R12, R16, R17: 0 k; 0603
R13: 20 k; 0603
R14: 6.98 k; 0603
R15: 20.5 k; 0603
U1: LM3671-407564
U2: LM3224; MSOP-8
U$2: AUDIOJACK
U$4: LM3658
U$7: FCI10118192-0001LF
USB: HEADER-5; NON-5
XBEE: HEADER-5; NON-5

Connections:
BOOSTOUT: C21.1, D1.C, R15.1, R16.1
BSTSHDWN: IC.18 (P3[7]), U2.3 (SHDN)
DATA: IC1.16 (R1IN), R10.1, U$2.P$3
DATA_R: IC.28 (P0[4]), IC1.15 (R1OUT)
ENREG: IC.27 (P0[3]), U1.P$1 (EN), U$4.P$5 (EN)
GND: C2.2, C3.2, C4.2, C5.2, C6.2, C7.2, C8.2, C9.2, C10.2, C11.2, C12.2, C13.2, C14.2, C15.2, C18.2, C19.2, C20.2, C21.2, C22.2, C23.2, CN1.GND (GNDBREAK), CN1.GNDBREAK (GND), CN2.2 (1), IC.1 (VSS), IC.10 (VSS), IC.36 (VSSA), IC1.18 (GND), IRSENSOR.1 (GROUND), R2.2, R3.1, R4.2, R5.1, R6.2, R14.1, U1.P$2 (PGND), U1.P$5 (SGND), U2.4 (GND), U2.7 (FSLCT), U$2.P$1, U$4.P$3 (GND), U$7.P5 (GND), XBEE.4 (PIN4)
unnamed: C4.1, C5.1, C23.1, CN2.1 (2), L2.1, R17.1, U1.P$3 (VIN), U2.6 (VIN), U$4.P$10 (BATT)
unnamed: R3.2, U$4.P$8 (I_SET)
unnamed: L1.1, U1.P$4 (SW)
unnamed: IC1.1 (EN/), R5.2
unnamed: C6.1, CN1.PWR1 (PWR), U$4.P$1 (CHG_IN)
unnamed: C1.1, C2.1, R1.2, R2.1, U1.P$6 (FB)
unnamed: C7.1, U$4.P$2 (USB_PWR), U$7.P1 (VCC)
unnamed: R4.1, U$4.P$9 (TS)
unnamed: R13.2, U2.1 (VC)
unnamed: C12.1, C13.1, IC.35 (VDDA), R11.2
unnamed: U$4.P$6 (STAT2), USB.2 (PIN2)
unnamed: U$4.P$7 (STAT1), USB.1 (PIN1)
unnamed: C17.2, IC1.6 (C2-)
unnamed: C8.1, IC.19 (VDDD)
unnamed: C9.1, IC.33 (VCCD)
unnamed: C17.1, IC1.5 (C2+)
unnamed: R9.2, U$2.P$4
unnamed: R10.2, U$2.P$5
unnamed: C16.2, IC1.4 (C1-)
unnamed: C16.1, IC1.2 (C1+)
unnamed: C14.1, IC1.3 (V+)
unnamed: C15.1, IC1.7 (V-)
unnamed: IC1.20 (SHDN/), R6.1
unnamed: C10.1, C11.1, IC.34 (VDDD), R12.2
unnamed: C20.1, R13.1
unnamed: D1.A, L2.2, U2.5 (SW)
unnamed: R9.1, R16.2, R17.2, U$2.P$2
unnamed: R14.2, R15.2, U2.2 (FB)
unnamed: C22.1, U2.8 (SS)
P3V3: C1.2, C3.1, C18.1, C19.1, IC1.19 (VCC), IRSENSOR.2 (VDD), L1.2, R1.1, R7.1, R8.1, R11.1, R12.1, XBEE.5 (PIN5)
SCL: IC.20 (P4[0]), IRSENSOR.4 (SCL), R7.2
SDA: IC.21 (P4[1]), IRSENSOR.3 (SDA), R8.2
USB_SEL: IC.30 (P0[6]), U$4.P$4 (USB_SEL)
XBEE_RX: IC.12 (P3[1]), XBEE.2 (PIN2)
XBEE_TX: IC.11 (P3[0]), XBEE.3 (PIN3)

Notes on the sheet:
Boost Power
XBee
PSoC
IR Sensor
RS-232 Transceiver
Soil Sensor
USB

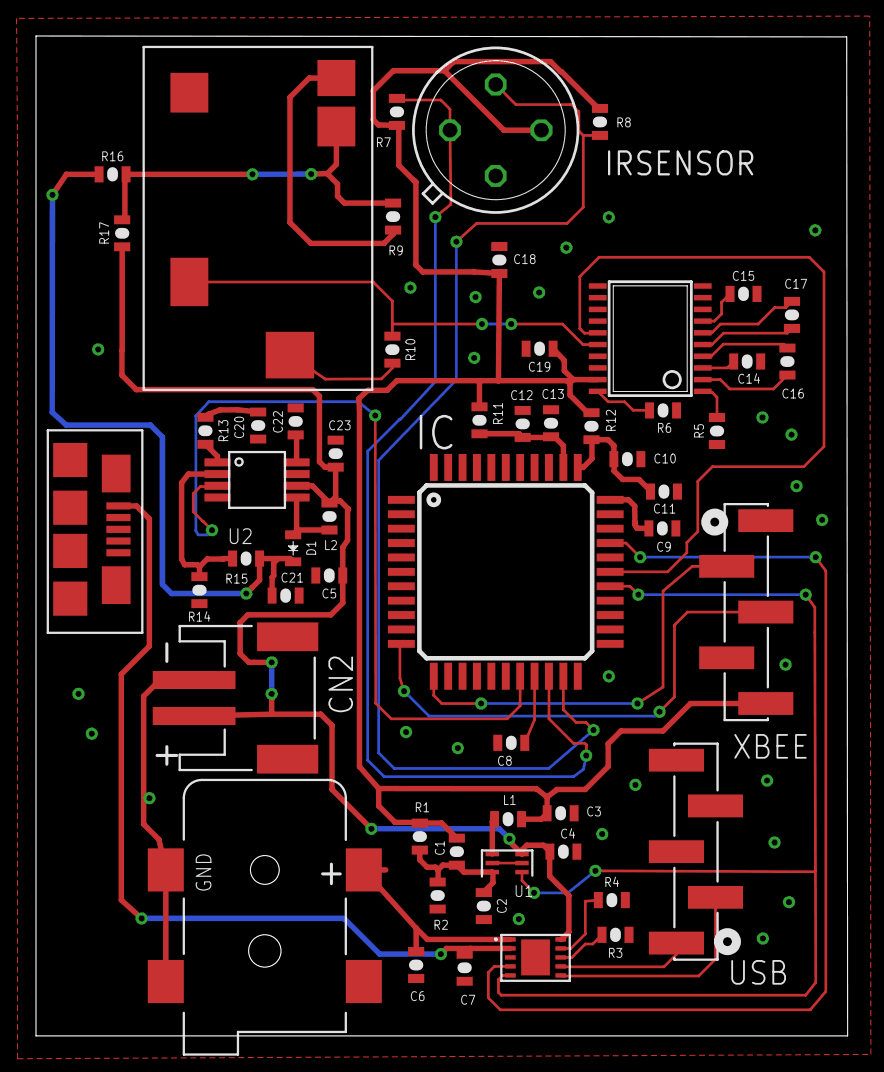
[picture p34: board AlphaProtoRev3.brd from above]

Board: 2 copper layers, 45.1 x 55.5 mm, 55 parts (0 on the bottom side), 41 nets.

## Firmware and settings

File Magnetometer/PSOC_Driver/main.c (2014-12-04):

/* ========================================
 *
 * Copyright YOUR COMPANY, THE YEAR
 * All Rights Reserved
 * UNPUBLISHED, LICENSED SOFTWARE.
 *
 * CONFIDENTIAL AND PROPRIETARY INFORMATION
 * WHICH IS THE PROPERTY OF your company.
 *
 * ========================================
*/
#include <project.h>
//#include "my_command_isr.h"
#include "my_command_isr.h"

//#include "DriverMAG3110.h"

//uint8 DataReady = 0xFF; /* Signal from PSOC to MATLAB when INT1 goes high */
uint8 Command_Received;
uint8 ReadyForCommand_Flag; /*If ready to receive new CMD, set to 1. else, set to 0.*/
uint8 IncomingData_Flag;
uint8 StatusError_Flag; /* Maybe unecessary since if status!=0, readyforcmd flag will never be raised and will prevent further cmds*/
uint8 MAG_DataRdy_Flag;
uint8 Global_ReadBuffer[8] = {0};
uint8 *Global_ReadPtr = Global_ReadBuffer;
uint8 DataInBuffer_Global[8] = {0};
uint8 *DataInPtr_Global = DataInBuffer_Global;
//uint8 WaitForDataRead_Flag;
uint8 Command_Buffer;
//#define CMD_I_RM_MAGDATA_D		(0x34u)


int main()
{    
	CyGlobalIntEnable; /* Uncomment this line to enable global interrupts. */
	XBee_UART_Start();
	I2C_Start();
	LCD_Start();
	
	//	INITIALIZE VALUES
	Command_Received = 0;
	MAG_DataRdy_Flag = 0;
	ReadyForCommand_Flag = 1;
	IncomingData_Flag = 0;
	StatusError_Flag = 0;
	//WaitForDataRead_Flag = 0;
	Command_Buffer = 0;
	
	// INITIALIZE ISRs
	InitXBee_Isr();
	//InitINT1_Isr(); // IF INT1 TRIGGERS WHEN NOT IN ACTIVE MODE, MOVE INITIATION CODE FOR SETTING ACTIVE.
	//INT1_isr_Start();
	
	XBee_UART_ClearRxBuffer();
	XBee_UART_ClearTxBuffer();
	CyDelay(2000);
	LCD_ClearDisplay();
	LCD_Position(0,0);
	LCD_PrintString("MAG DRIVER:");
	LCD_Position(1,0);
	LCD_PrintString("[ERR]");
	LCD_Position(1,7);
	LCD_PrintString("[I2C]");

	uint8 status = 0;
	status = SetCtrlReg1Default();
	status |= SetCtrlReg2Default();
	if(status !=0)
	{
		LCD_ClearDisplay();
		LCD_Position(0,0);
		LCD_PrintInt8(status);
		status = 0;
	}
	uint8 pin_status = 0;
	    
    for(;;)
    {
		pin_status = INT1_Pin_Read();
		pin_status |= MAG_DataRdy_Flag;
		if(pin_status)
		{
			MAG_DataRdy_Flag = pin_status;
			if(ReadyForCommand_Flag!=0)
			{
				Command_Received = CMD_I_RM_MAGDATA;
				ReadyForCommand_Flag = 0;
			}	
		}

		if(Command_Received != 0)
		{
			LCD_ClearDisplay();
			//XBee_UART_ClearTxBuffer();
			//XBee_UART_ClearRxBuffer();			
			switch (Command_Received){
				case CMD_I_RM_MAGDATA: // CMD_I_RM_MAGDATA = 34
				{
					status = ReadMagData(Global_ReadPtr);
					if(status == 0)
					{
						CyDelay(500);
						XBee_UART_PutChar(Command_Received);
						//LED_out_Write(0);
						CyDelay(500);
						XBee_UART_PutArray(Global_ReadPtr,ARRAY_SIZE_MAG_DATA);
						CyDelay(1000);					
						//WaitForDataRead_Flag = 0;
						MAG_DataRdy_Flag = 0;
						if(Command_Buffer!=0)
						{
							Command_Received = Command_Buffer;
							Command_Buffer = 0;
							//ReadyForCommand_Flag = 0; //Dont toggle flag
						}
						else
						{
							Command_Received = 0;
							ReadyForCommand_Flag = 1;
							LED_out_Write(0);
						}
					}					
					else 
					{
						// will result is a halt of CMD processing and leaves LED lit (visual error signal)
						LCD_Position(1,0);
						LCD_PrintString("E:STA");
						CyDelay(1000);		
						StatusError_Flag = 1;						
					}
				}
				break;
				
				case CMD_I_WM_OFFSET_ALL:// CMD_I_WM_OFFSET_ALL = 1
				{
					if(IncomingData_Flag == 0) // IF THE OFFSET DATA TO WRITE HAS BEEN RECEIVED...
					{
						status = WriteOffsetCorrection(DataInPtr_Global);
						if(status == 0)
						{
							CyDelay(500);
							XBee_UART_PutChar(Command_Received); //Sends confirmation TWICE. Once after receiving CMD, and again after finishing WRITE
							LED_out_Write(0);
							Command_Received = 0;
							IncomingData_Flag = 0;
							ReadyForCommand_Flag = 1;
						}					
						else 
						{
							// will result is a halt of CMD processing and leaves LED lit (visual error signal)
							LCD_Position(1,0);
							LCD_PrintString("E:STA");
							CyDelay(1000);		
							StatusError_Flag = 1;
						}
					}
				}
				break;
				
				case CMD_I_RS_CTRL1://CMD_I_RS_CTRL1=35
				{
					status = ReadCtrlReg1(Global_ReadPtr);
					if(status == 0)
					{
						CyDelay(500);
						XBee_UART_PutChar(Command_Received);
						LED_out_Write(0);
						CyDelay(500);
						XBee_UART_PutChar(Global_ReadBuffer[0]); // Send Read Value
						Command_Received = 0;
						IncomingData_Flag = 0;
						ReadyForCommand_Flag = 1;
					}					
					else 
					{
						// will result is a halt of CMD processing and leaves LED lit (visual error signal)
						LCD_Position(1,0);
						LCD_PrintString("E:STA");
						CyDelay(1000);		
						StatusError_Flag = 1;
					}				
				}
				break;
				
				case CMD_I_RS_CTRL2://CMD_I_RS_CTRL2 = 36
				{
					status = ReadCtrlReg2(Global_ReadPtr);
					if(status == 0)
					{
						CyDelay(500);
						XBee_UART_PutChar(Command_Received);
						LED_out_Write(0);
						CyDelay(500);
						XBee_UART_PutChar(Global_ReadBuffer[0]); // Send Read Value
						Command_Received = 0;
						IncomingData_Flag = 0;
						ReadyForCommand_Flag = 1;
					}					
					else 
					{
						// will result is a halt of CMD processing and leaves LED lit (visual error signal)
						LCD_Position(1,0);
						LCD_PrintString("E:STA");
						CyDelay(1000);		
						StatusError_Flag = 1;
					}	
				}
				break;
				
				case CMD_I_RS_DRSTATUS://CMD_I_RS_DRSTATUS = 37
				{
					status = ReadDrStatus(Global_ReadPtr);
					if(status == 0)
					{
						CyDelay(500);
						XBee_UART_PutChar(Command_Received);
						LED_out_Write(0);
						CyDelay(500);
						XBee_UART_PutChar(Global_ReadBuffer[0]); // Send Read Value
						Command_Received = 0;
						IncomingData_Flag = 0;
						ReadyForCommand_Flag = 1;
					}					
					else 
					{
						// will result is a halt of CMD processing and leaves LED lit (visual error signal)
						LCD_Position(1,0);
						LCD_PrintString("E:STA");
						CyDelay(1000);		
						StatusError_Flag = 1;
					}	
				}
				break;
				
				case CMD_I_RS_SYSMOD:// CMD_I_RS_SYSMOD = 38
				{
					status = ReadSysMod(Global_ReadPtr);
					if(status == 0)
					{
						CyDelay(500);
						XBee_UART_PutChar(Command_Received);
						LED_out_Write(0);
						CyDelay(500);
						XBee_UART_PutChar(Global_ReadBuffer[0]);
						Command_Received = 0;
						IncomingData_Flag = 0;
						ReadyForCommand_Flag = 1;
					}					
					else 
					{
						// will result is a halt of CMD processing and leaves LED lit (visual error signal)
						LCD_Position(1,0);
						LCD_PrintString("E:STA");
						CyDelay(1000);		
						StatusError_Flag = 1;
					}
				}
				break;
				
				case CMD_I_RS_DIETEMP: // CMD_I_RS_DIETEMP = 39
				{
					status = ReadDieTemp(Global_ReadPtr);
					if(status == 0)
					{
						CyDelay(500);
						XBee_UART_PutChar(Command_Received);
						LED_out_Write(0);
						CyDelay(500);
						XBee_UART_PutChar(Global_ReadBuffer[0]);
						Command_Received = 0;
						IncomingData_Flag = 0;
						ReadyForCommand_Flag = 1;
					}					
					else 
					{
						// will result is a halt of CMD processing and leaves LED lit (visual error signal)
						LCD_Position(1,0);
						LCD_PrintString("E:STA");
						CyDelay(1000);		
						StatusError_Flag = 1;
					}
				}
				break;
				
				case CMD_I_RS_WHOAMI: // CMD_I_RS_WHOAMI = 40
				{
					status = ReadWhoAmI(Global_ReadPtr);
					if(status == 0)
					{
						CyDelay(500);
						XBee_UART_PutChar(Command_Received);
						LED_out_Write(0);
						CyDelay(500);
						XBee_UART_PutChar(Global_ReadBuffer[0]);
						Command_Received = 0;
						IncomingData_Flag = 0;
						ReadyForCommand_Flag = 1;
					}					
					else 
					{
						// will result is a halt of CMD processing and leaves LED lit (visual error signal)
						LCD_Position(1,0);
						LCD_PrintString("E:STA");
						CyDelay(1000);		
						StatusError_Flag = 1;
					}
				}
				break;
				
				case CMD_I_WS_CTRL1_DEFAULT: // CMD_I_WS_CTRL1_DEFAULT = 41
				{
					status = SetCtrlReg1Default();
					if(status == 0) //if the write was a success
					{
						CyDelay(500);
						XBee_UART_PutChar(Command_Received);//Returns command received from MATLAB as confirmation
						LED_out_Write(0); //Turns off LED
						Command_Received = 0; //Clears the Command
						IncomingData_Flag = 0;
						ReadyForCommand_Flag = 1; // Sets state as READY for next command
					}					
					else 
					{
						// will result is a halt of CMD processing and leaves LED lit (visual error signal)
						LCD_Position(1,0);
						LCD_PrintString("E:STA");
						CyDelay(1000);		
						StatusError_Flag = 1;
					}
				}
				break;
				
				case CMD_I_WS_CTRL1_MODSTANDBY: // CMD_I_WS_CTRL1_MODSTANDBY = 42
				{
					status = SetStandbyMode();
					if(status == 0) //if the write was a success
					{
						CyDelay(500);
						XBee_UART_PutChar(Command_Received);//Returns command received from MATLAB as confirmation
						LED_out_Write(0); //Turns off LED
						Command_Received = 0; //Clears the Command
						IncomingData_Flag = 0;
						ReadyForCommand_Flag = 1; // Sets state as READY for next command
					}					
					else 
					{
						// will result is a halt of CMD processing and leaves LED lit (visual error signal)
						LCD_Position(1,0);
						LCD_PrintString("E:STA");
						CyDelay(1000);		
						StatusError_Flag = 1;
					}
				}
				break;
				
				case CMD_I_WS_CTRL1_MODSINGLE: // CMD_I_WS_CTRL1_MODSINGLE = 43
				{
					status = SetSingleMeasurmentMode();
					if(status == 0) //if the write was a success
					{
						CyDelay(500);
						XBee_UART_PutChar(Command_Received);//Returns command received from MATLAB as confirmation
						LED_out_Write(0); //Turns off LED
						Command_Received = 0; //Clears the Command
						IncomingData_Flag = 0;
						ReadyForCommand_Flag = 1; // Sets state as READY for next command
					}					
					else 
					{
						// will result is a halt of CMD processing and leaves LED lit (visual error signal)
						LCD_Position(1,0);
						LCD_PrintString("E:STA");
						CyDelay(1000);		
						StatusError_Flag = 1;
					}
				}
				break;
				
				//IF INT1 CONTINUES TO TRIGGER WHEN NOT IT ACTIVE MODE, DEACTIVATE/ACTIVATE ISR WHEN CHANGING MODES				
				case CMD_I_WS_CTRL1_MODACTIVE: // CMD_I_WS_CTRL1_MODACTIVE = 44
				{
					status = SetContinuousMode();
					if(status == 0) //if the write was a success
					{
						CyDelay(500);
						XBee_UART_PutChar(Command_Received);//Returns command received from MATLAB as confirmation
						LED_out_Write(0); //Turns off LED
						Command_Received = 0; //Clears the Command
						IncomingData_Flag = 0;
						ReadyForCommand_Flag = 1; // Sets state as READY for next command
					}					
					else 
					{
						// will result is a halt of CMD processing and leaves LED lit (visual error signal)
						LCD_Position(1,0);
						LCD_PrintString("E:STA");
						CyDelay(1000);		
						StatusError_Flag = 1;
					}
				}
				break;
				
				case CMD_I_WS_CTRL1_MODTRIGGER: // CMD_I_WS_CTRL1_MODTRIGGER = 45
				{
					status = SetTriggerMeasurmentMode();
					if(status == 0) //if the write was a success
					{
						CyDelay(500);
						XBee_UART_PutChar(Command_Received);//Returns command received from MATLAB as confirmation
						LED_out_Write(0); //Turns off LED
						Command_Received = 0; //Clears the Command
						IncomingData_Flag = 0;
						ReadyForCommand_Flag = 1; // Sets state as READY for next command
					}					
					else 
					{
						// will result is a halt of CMD processing and leaves LED lit (visual error signal)
						LCD_Position(1,0);
						LCD_PrintString("E:STA");
						CyDelay(1000);		
						StatusError_Flag = 1;
					}
				}
				break;
				
				case CMD_I_WS_CTRL1_ENFAST: // CMD_I_WS_CTRL1_ENFAST = 46
				{
					status = SetFastReadOn();
					if(status == 0) //if the write was a success
					{
						CyDelay(500);
						XBee_UART_PutChar(Command_Received);//Returns command received from MATLAB as confirmation
						LED_out_Write(0); //Turns off LED
						Command_Received = 0; //Clears the Command
						IncomingData_Flag = 0;
						ReadyForCommand_Flag = 1; // Sets state as READY for next command
					}					
					else 
					{
						// will result is a halt of CMD processing and leaves LED lit (visual error signal)
						LCD_Position(1,0);
						LCD_PrintString("E:STA");
						CyDelay(1000);		
						StatusError_Flag = 1;
					}
				}
				break;
				
				case CMD_I_WS_CTRL1_NENFAST: //CMD_I_WS_CTRL1_NENFAST = 47
				{
					status = SetFastReadOff();
					if(status == 0) //if the write was a success
					{
						CyDelay(500);
						XBee_UART_PutChar(Command_Received);//Returns command received from MATLAB as confirmation
						LED_out_Write(0); //Turns off LED
						Command_Received = 0; //Clears the Command
						IncomingData_Flag = 0;
						ReadyForCommand_Flag = 1; // Sets state as READY for next command
					}					
					else 
					{
						// will result is a halt of CMD processing and leaves LED lit (visual error signal)
						LCD_Position(1,0);
						LCD_PrintString("E:STA");
						CyDelay(1000);		
						StatusError_Flag = 1;
					}
				}
				break;
				
				case CMD_I_WS_CTRL2_DEFAULT: //CMD_I_WS_CTRL2_DEFAULT = 48
				{
					status = SetCtrlReg2Default();
					if(status == 0) //if the write was a success
					{
						CyDelay(500);
						XBee_UART_PutChar(Command_Received);//Returns command received from MATLAB as confirmation
						LED_out_Write(0); //Turns off LED
						Command_Received = 0; //Clears the Command
						IncomingData_Flag = 0;
						ReadyForCommand_Flag = 1; // Sets state as READY for next command
					}					
					else 
					{
						// will result is a halt of CMD processing and leaves LED lit (visual error signal)
						LCD_Position(1,0);
						LCD_PrintString("E:STA");
						CyDelay(1000);		
						StatusError_Flag = 1;
					}
				}
				break;
				
				case CMD_I_WS_CTRL2_ENAUTORESET: // CMD_I_WS_CTRL2_ENAUTORESET = 49
				{
					status = SetAutoResetOn();
					if(status == 0) //if the write was a success
					{
						CyDelay(500);
						XBee_UART_PutChar(Command_Received);//Returns command received from MATLAB as confirmation
						LED_out_Write(0); //Turns off LED
						Command_Received = 0; //Clears the Command
						IncomingData_Flag = 0;
						ReadyForCommand_Flag = 1; // Sets state as READY for next command
					}					
					else 
					{
						// will result is a halt of CMD processing and leaves LED lit (visual error signal)
						LCD_Position(1,0);
						LCD_PrintString("E:STA");
						CyDelay(1000);		
						StatusError_Flag = 1;
					}
				}
				break;
				
				case CMD_I_WS_CTRL2_NENAUTORESET: // CMD_I_WS_CTRL2_NENAUTORESET = 50
				{
					status = SetAutoResetOff();
					if(status == 0) //if the write was a success
					{
						CyDelay(500);
						XBee_UART_PutChar(Command_Received);//Returns command received from MATLAB as confirmation
						LED_out_Write(0); //Turns off LED
						Command_Received = 0; //Clears the Command
						IncomingData_Flag = 0;
						ReadyForCommand_Flag = 1; // Sets state as READY for next command
					}					
					else 
					{
						// will result is a halt of CMD processing and leaves LED lit (visual error signal)
						LCD_Position(1,0);
						LCD_PrintString("E:STA");
						CyDelay(1000);		
						StatusError_Flag = 1;
					}
				}
				break;
				
				case CMD_I_WS_CTRL2_ENUSEROFFSET: // CMD_I_WS_CTRL2_ENUSEROFFSET = 51
				{
					status = SetUserCorrectedData();
					if(status == 0) //if the write was a success
					{
						CyDelay(500);
						XBee_UART_PutChar(Command_Received);//Returns command received from MATLAB as confirmation
						LED_out_Write(0); //Turns off LED
						Command_Received = 0; //Clears the Command
						IncomingData_Flag = 0;
						ReadyForCommand_Flag = 1; // Sets state as READY for next command
					}					
					else 
					{
						// will result is a halt of CMD processing and leaves LED lit (visual error signal)
						LCD_Position(1,0);
						LCD_PrintString("E:STA");
						CyDelay(1000);		
						StatusError_Flag = 1;						
					}
				}
				break;
				
				case CMD_I_WS_CTRL2_NENUSEROFFSET: // CMD_I_WS_CTRL2_NENUSEROFFSET = 52
				{
					status = SetRawData();
					if(status == 0) //if the write was a success
					{
						CyDelay(500);
						XBee_UART_PutChar(Command_Received);//Returns command received from MATLAB as confirmation
						LED_out_Write(0); //Turns off LED
						Command_Received = 0; //Clears the Command
						IncomingData_Flag = 0;
						ReadyForCommand_Flag = 1; // Sets state as READY for next command
					}					
					else 
					{
						// will result is a halt of CMD processing and leaves LED lit (visual error signal)
						StatusError_Flag = 1;
						LCD_Position(1,0);
						LCD_PrintString("E:STA");
						CyDelay(1000);		
						StatusError_Flag = 1;						
					}
				}
				break;				
				
				case CMD_I_WS_CTRL2_RESETMAG: // CMD_I_WS_CTRL2_RESETMAG = 53
				{
					status = ResetMag();
					if(status == 0) //if the write was a success
					{
						CyDelay(1000); //LET MAGNETOMETER RESET PROCEDURE FINISH
						XBee_UART_PutChar(Command_Received);//Returns command received from MATLAB as confirmation
						LED_out_Write(0); //Turns off LED
						Command_Received = 0; //Clears the Command
						IncomingData_Flag = 0;
						ReadyForCommand_Flag = 1; // Sets state as READY for next command
					}					
					else 
					{
						// will result is a halt of CMD processing and leaves LED lit (visual error signal)
						//LCD_ClearDisplay();
						LCD_Position(1,0);
						LCD_PrintString("E:STA");
						CyDelay(1000);		
						StatusError_Flag = 1;
					}
				}
				break;
				
				case CMD_I_RESET_ALL://54
				{
					// RESET I2C
					uint8 i2c_status = I2C_MasterClearStatus();
					//LCD_ClearDisplay();
					LCD_Position(1,7);
					LCD_PrintInt8(i2c_status);
					
					I2C_MasterClearReadBuf();
					I2C_MasterClearWriteBuf();
					
					// Reset MAG CTRL REGISTERS
					status = SetCtrlReg1Default();
					status |= SetCtrlReg2Default();
					if(status == 0) //if the write was a success
					{
						CyDelay(500);
						XBee_UART_PutChar(Command_Received);//Returns command received from MATLAB as confirmation
						LED_out_Write(0); //Turns off LED
						Command_Received = 0; //Clears the Command
						IncomingData_Flag = 0;
						ReadyForCommand_Flag = 1; // Sets state as READY for next command
					}
					else 
					{
						// will result is a halt of CMD processing and leaves LED lit (visual error signal)
						//LCD_ClearDisplay();
						LCD_Position(1,0);
						LCD_PrintString("E:STA");
						CyDelay(1000);		
						StatusError_Flag = 1;
					}					
					
				}
				break;
				
				default: //handles Set Sampling/Data rate CMDs, and Out of range errors
				{
					if((Command_Received >= (STARTOFRANGE_SET_SAMPLING_AND_RATE))&&(Command_Received < (STARTOFRANGE_SET_SAMPLING_AND_RATE + RANGESIZE_SET_SAMPLING_AND_RATE)))
					{
						uint8 offset = Command_Received-STARTOFRANGE_SET_SAMPLING_AND_RATE;
						offset *=DELTAVALS_SET_SAMP_AND_RATE;
						status = SetOverSampleAndDataRate(offset);
						if(status == 0) //if the write was a success
						{
							CyDelay(500);
							XBee_UART_PutChar(Command_Received);//Returns command received from MATLAB as confirmation
							LED_out_Write(0); //Turns off LED
							Command_Received = 0; //Clears the Command
							IncomingData_Flag = 0;
							ReadyForCommand_Flag = 1; // Sets state as READY for next command
						}		
						else 
						{
							// will result is a halt of CMD processing and leaves LED lit (visual error signal)
							StatusError_Flag = 1;
							//LCD_ClearDisplay();
							LCD_Position(1,0);
							LCD_PrintString("E:STA");
							CyDelay(1000);
						}
					}
					else // ERROR: CMD VALUE OUT OF RANGE (executed if not a CMD to set sampling/data rate)
					{
						//CLEAR EVERYTHING
						XBee_UART_ClearTxBuffer();
						XBee_UART_ClearRxBuffer();
						I2C_MasterClearReadBuf();
						I2C_MasterClearWriteBuf();

						Command_Received = 0; //Clears the Command
						IncomingData_Flag = 0;
						ReadyForCommand_Flag = 1; // Sets state as READY for next command						
						XBee_UART_PutChar(CMD_O_CMDVALUEOUTOFRANGE); //Send error msg
						//LCD_ClearDisplay();
						LCD_Position(1,0);
						LCD_PrintString("E:RAN");
						CyDelay(1000);
						LED_out_Write(0); //Turns off LED
					}
				}			
			} //END OF SWITCH-CASE
		}//end of IF statement encasing switch-case
		
		/*else // if(Command_Received == 0)
		{
			if((MAG_DataRdy_Flag==1) && (WaitForDataRead_Flag==0))
			{
				//May change CMD_O_MAGDATARDY to simply be the same as CMD_I_RM_MAGDATA.
				//XBee_UART_ClearTxBuffer();
				//LCD_ClearDisplay();
				LCD_Position(1,0);
				LCD_PrintString("DRDY2");
				XBee_UART_PutChar(CMD_O_MAGDATARDY);// CMD_O_MAGDATARDY = 55
				WaitForDataRead_Flag = 1; //Prevents constant resending of notification to MATLAB
				INT1_isr_Disable();
			}
		}*/
	}//END OF FOR LOOP	
		
}//END OF MAIN

/* [] END OF FILE */

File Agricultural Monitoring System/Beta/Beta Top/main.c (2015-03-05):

/* ========================================
 *
 * Copyright YOUR COMPANY, THE YEAR
 * All Rights Reserved
 * UNPUBLISHED, LICENSED SOFTWARE.
 *
 * CONFIDENTIAL AND PROPRIETARY INFORMATION
 * WHICH IS THE PROPERTY OF your company.
 *
 * ========================================
*/
#include <project.h>
#include <stdio.h>
#include "MLX.h"
#include "utils.h"
#include "stem_isr.h"

//State Definitions.
#define WAKE 0            
#define GETDATA 1
#define TXDATA 2
#define SLEEPMODE 3

//number of levels (depths)
#define NUM_LEVELS 1

//Time asleep ~= 4 seconds
uint8 wakeCycles = 8;

//Vegetronix Definitions
uint8 state;
double voltage[NUM_LEVELS];
uint16 value;
char Veg_out[16];

//Temperature Definitions
double temperature[NUM_LEVELS];
char temp_out[6];
int main()
{
    //Enable custom ISR's
    initAllISR();
    
    //Enable Globals
    CyGlobalIntEnable;    
    
    //INITIALIZE 12C, XBEE, Veg
    Veg_Start();
    Veg_StartConvert();
    Xbee_UART_Start();
    I2C_1_Start();   
    CyDelay(250);
    
    //read EEPROM, config, and oscillator trimming value
    readEEPROM();
    writeOscTrimValue();
    writeConfigValue();
    
    //Initialize PSOC state
    state = WAKE;
    
    //Start Sleep Timer 
    SleepTimer_Start();
    
    
    for(;;)
    {
        /* Place your application code here. */
        if (state == WAKE){
            
            //change state
            state = GETDATA;
        } // end WAKE
        
        else if (state == GETDATA){
            
            //MLX READ------------------------------------------
            //Temperature, compensation, and whole frame read
            uint16 ptat = readPTAT();          
            uint16 comp = readCompensation();
            readFrame();    
            //END MLX READ--------------------------------------

            //VEG READ------------------------------------------
            //Get and scale ADC
            int depth;
            for (depth = 0; depth < NUM_LEVELS; depth++) {
                voltage[depth] = Veg_GetResult16(0)*(3.3/4096);
                temperature[depth] = 22.3;
            }
            
            
            
            //END VEG READ--------------------------------------
            
            //change state
            state = TXDATA;
        } // end GETDATA
        
        else if (state == TXDATA){
            
            //TX MLX
            //tx whole frame, PTAT, and compensation
            XBeeTxFrame();
            XBeeTxPTAT();
            XBeeTxCompensation();
            //END TX MLX----------------------------------------
            
            //TX VEG--------------------------------------------
            char level[4];
            int depth;
            //string for calculating Checksum
            char toCksm[56];
            Xbee_UART_PutString("V,");
            
            for (depth = 0; depth < NUM_LEVELS; depth++) {
                sprintf(level, "%d:", depth);
                sprintf(Veg_out, "%1.4f:", voltage[depth]);
                //Add hard coded temperature value
                sprintf(temp_out, "%2.1f,", temperature[depth]);
                //if first level, copy string, otherwise concatenate
                if (depth == 0) {
                    strcpy(toCksm, level);    
                }
                else {
                    strcat(toCksm, level);
                }
                
                strcat(toCksm, Veg_out);
                strcat(toCksm, temp_out);
                
                //Transmit level string
                Xbee_UART_PutString(level);
                Xbee_UART_PutString(Veg_out);
                Xbee_UART_PutString(temp_out);
            }       //end for
            
            //Transmit Checksum for Vegetronix
             Xbee_UART_PutChar(calculateCheckSum(toCksm, strlen(toCksm)));
            
            //END TX VEG----------------------------------------
            
            //Change State
            state = SLEEPMODE;
        } // end TXDATA
        
        else if (state == SLEEPMODE){
            //put her to sleep
            //CyDelay(2000);
            if (wake_count % wakeCycles == 0) {
                //Change State
                state = WAKE;
                continue;
            }
            else {
                sleepPsoc();   
            }
            
            
        } // END SLEEPM0DE
        
        else{ // Error in state machine, to be filled out. Likely a reset will occur here. 
            
            //Change State
            state = WAKE;
        } // End Error Catch
        
    }
}

/* [] END OF FILE */

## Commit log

2014-12-04 latest driver
2014-12-05 updated main and MAG3110 driver for register write offset
2014-12-18 Uploaded Alpha Prototype PCB
    [AlphaProtoRev3.brd, AlphaProtoRev3.sch]
2014-12-18 Added Bill of Materials and README.md
2014-12-18 Added screenshot of top design pcbs
2014-12-18 Changed README.md to use board layout
2014-12-18 adding bom table to read
2014-12-18 added bom png
2014-12-25 Changed name from Agricultural Monitor
    [AlphaProtoRev3.brd, AlphaProtoRev3.sch]
2014-12-25 fixed schematic links in alpha proto
2014-12-31 Added driver folder for sensor and post drivers
2015-01-05 started SDI-12 driver for PSoC to Decagon sensor communication
2015-01-05 skeleton driver. Is git push necessary?
2015-01-10 Added IR sensor to main components
2015-01-14 MLX Driver
    Only works for getting raw IR/Temperature data. Need to further process
    data on external program for useful information.
2015-01-15 Added sample java application for GUI. Moved MLX cypress project to proper folder under data logger
2015-01-16 separated app functionality from digi device commands and other functions
2015-01-20 client side authentication issues forced me to create a python application for using Device Cloud's API
2015-01-20 can query device settings, device status, and list all data streams
2015-02-13 Added d3 dependency and new factory for parsing sensor node data
2015-02-24 PSOC5 sleep timer code
2015-02-24 Added UART for XBee tests
2015-02-26 synchronized data with collected sensor data stored in firebase
2015-02-27 Beta main with correct formatting for beaglebone
    [main.c]
2015-03-03 Added Beta PCB's
    So Jeff knows how to do it
    [BetaRev1.brd, BetaRev1.sch]
2015-03-11 Added Release board psoc files
2015-03-18 used doctoc to generate table of contents
    [ReleaseRev1.brd, ReleaseRev1.sch, pogoToProg.brd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]
2015-03-27 Create Spring Quarter Work
